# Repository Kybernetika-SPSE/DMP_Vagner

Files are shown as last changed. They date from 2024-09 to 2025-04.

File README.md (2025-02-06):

# Smart Hive

**Smart Hive** je projekt zaměřený na monitorování včelích úlů pomocí senzorů, které sbírají důležitá data o prostředí v úlech a jejich okolí. Data jsou přenášena přes I2C sběrnici do centrální (master) jednotky, která je dále odesílá do databáze. K těmto datům mohou uživatelé přistupovat online prostřednictvím webového rozhraní.

## Funkce
- **Sběr dat**: Senzory instalované ve včelích úlech monitorují teplotu, vlhkost, hmotnost úlu a hlukové znečištění.
- **Přenos dat**: Data z jednotlivých úlů jsou sbírána pomocí I2C komunikace a odesílána do centrální jednotky.
- **Uložení dat**: Centrální jednotka data ukládá do databáze.
- **Přístup k datům**: Uživatelé mohou přistupovat k datům online prostřednictvím webového rozhraní.

## Technické detaily
- **I2C komunikace**: Využívá se pro přenos dat mezi senzory v úlech a centrální jednotkou.
- **Databáze**: Data jsou ukládána do vzdálené databáze, která je přístupná uživatelům online.
- **Centrální jednotka**: Hlavní jednotka přijímá data od senzorů a zajišťuje jejich odesílání do databáze.
- **Webové rozhraní**: Poskytuje uživatelům přístup k živým datům a historickým záznamům.

## Požadavky
- **Hardware**: ESP32 s podporou I2C, senzory pro měření teploty, vlhkosti, hmotnosti a hluku, včelí úly.
- **Software**: Podpora I2C komunikace, databázový systém (např. MySQL, PostgreSQL), webový server pro přístup k datům.

## Použití
Po úspěšné instalaci systém začne shromažďovat a odesílat data ze senzorů v reálném čase. Uživatelé mohou k těmto datům přistupovat pomocí webového rozhraní, které umožňuje sledovat aktuální stav úlů a analyzovat historická data.

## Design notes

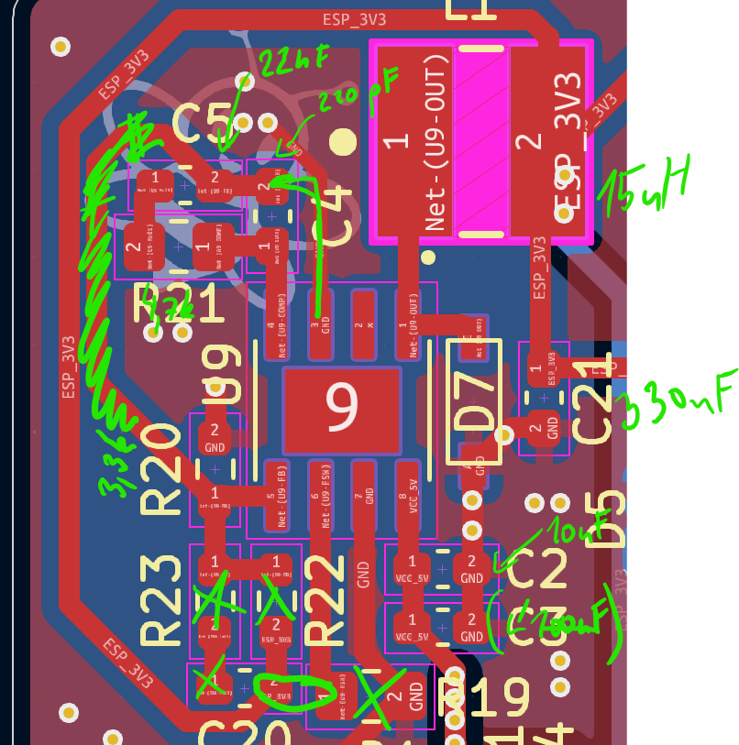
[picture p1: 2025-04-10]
PROJEKTOVÁ DATA/PCB/Master/Zapojení buck.png

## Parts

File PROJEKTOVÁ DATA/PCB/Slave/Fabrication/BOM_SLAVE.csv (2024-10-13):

Id | Designator | Footprint | Quantity | Designation | Supplier and ref
1 | J3 | PinSocket_1x07_P2.54mm_Vertical | 1 | Conn_01x07_Socket
2 | C17,C16 | C_0603_1608Metric_Pad1.08x0.95mm_HandSolder | 2 | 30pF
3 | C1,C3,C19,C4,C9,C5,C7 | C_0603_1608Metric_Pad1.08x0.95mm_HandSolder | 7 | 100nF
4 | C15,C20 | C_0603_1608Metric_Pad1.08x0.95mm_HandSolder | 2 | u1F
5 | R6,R7 | R_0603_1608Metric_Pad0.98x0.95mm_HandSolder | 2 | 5k1
6 | C6,C8,C14,C13,C11 | C_0603_1608Metric_Pad1.08x0.95mm_HandSolder | 5 | 1uF
7 | J1 | USB_C_Receptacle_GCT_USB4105-xx-A_16P_TopMnt_Horizontal | 1 | USB_C_Receptacle_USB2.0_16P
8 | ,,,,,,, |  | 8
9 | Q2 | SOT-23 | 1 | PNP
10 | U2 | SOP50P310X90-8N | 1 | TCA9406DC
11 | J2 | TerminalBlock_Phoenix_MPT-0,5-5-2.54_1x05_P2.54mm_Horizontal | 1 | Conn_01x05_Pin
12 | R12 | R_0603_1608Metric_Pad0.98x0.95mm_HandSolder | 1 | 120
13 | C18,C12 | C_0603_1608Metric_Pad1.08x0.95mm_HandSolder | 2 | 1uf
14 | J4 | PinHeader_1x04_P2.54mm_Vertical | 1 | Conn_01x04_Socket
15 | MK1 | InvenSense_ICS-43434-6_3.5x2.65mm | 1 | ICS-43434
16 | R17,R16 | R_0603_1608Metric_Pad0.98x0.95mm_HandSolder | 2 | R
17 | U3 | XDCR_BMP280 | 1 | BMP280
18 | J5 | PinHeader_1x07_P1.00mm_Vertical_SMD_Pin1Left | 1 | Conn_01x07_Socket
19 | U4 | SOIC127P599X175-8N | 1 | P82B715D
20 | SW1,SW2 | SW_PTS810_SJM_250_SMTR_LFS | 2 | PTS810_SJM_250_SMTR_LFS
21 | U5 | SOP-16_3.9x9.9mm_P1.27mm | 1 | HX711
22 | U1 | ESP32-S2-MINI-1 | 1 | ESP32-S3-MINI-1
23 | C2,C10 | C_0603_1608Metric_Pad1.08x0.95mm_HandSolder | 2 | 10uf
24 | R11,R9,R10 | R_0603_1608Metric_Pad0.98x0.95mm_HandSolder | 3 | 10k
25 | R8 | R_0603_1608Metric_Pad0.98x0.95mm_HandSolder | 1 | 0R
26 | U6 | SOIC127P599X175-8N | 1 | SN65HVD230
27 | D2 | Nexperia_CFP3_SOD-123W | 1 | 1N5819
28 | D3,D4,D1 | TVS_LESD5D5.0CT1G | 3 | LESD5D5.0CT1G
29 | R15 | R_0603_1608Metric_Pad0.98x0.95mm_HandSolder | 1 | 1k
30 | R13 | R_0603_1608Metric_Pad0.98x0.95mm_HandSolder | 1 | 20k
31 | R14 | R_0603_1608Metric_Pad0.98x0.95mm_HandSolder | 1 | 8k2
32 | D5 | LED_SK6812MINI_PLCC4_3.5x3.5mm_P1.75mm | 1 | SK6812MINI

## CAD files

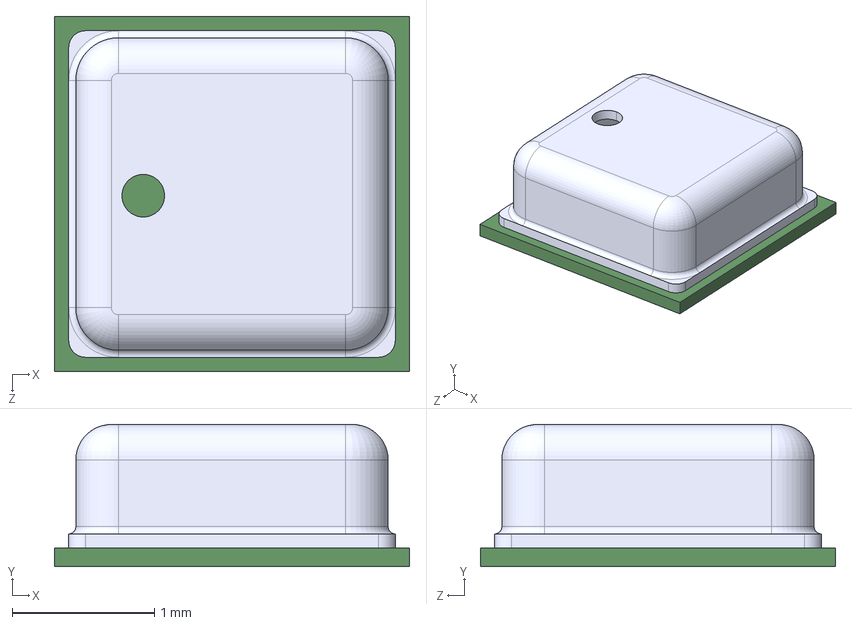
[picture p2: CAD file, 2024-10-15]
PROJEKTOVÁ DATA/PCB/Master/download/BME280/BME280.step
2.50 x 1.00 x 2.50 mm

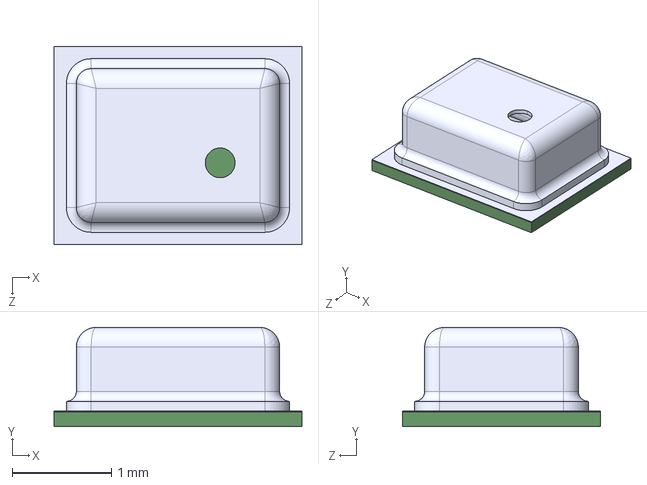
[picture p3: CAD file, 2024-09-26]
PROJEKTOVÁ DATA/PCB/Master/download/BMP280/BMP280.step
2.50 x 1.00 x 2.00 mm

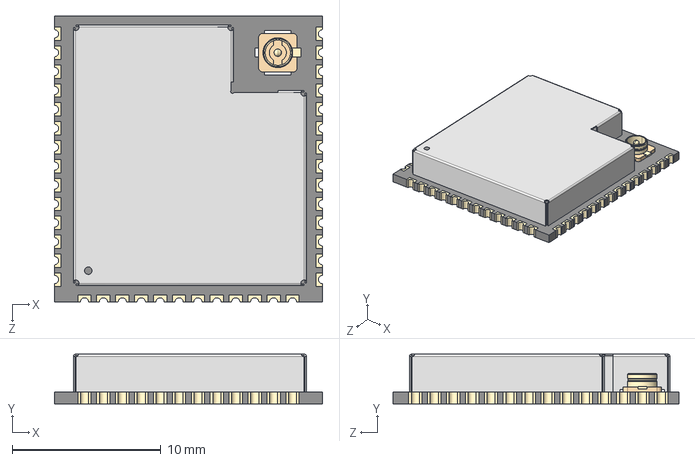
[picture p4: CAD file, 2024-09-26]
PROJEKTOVÁ DATA/PCB/Master/download/ESP32-S3-WROOM-1U/ESP32-S3-WROOM-1U.step
18.0 x 3.35 x 19.2 mm

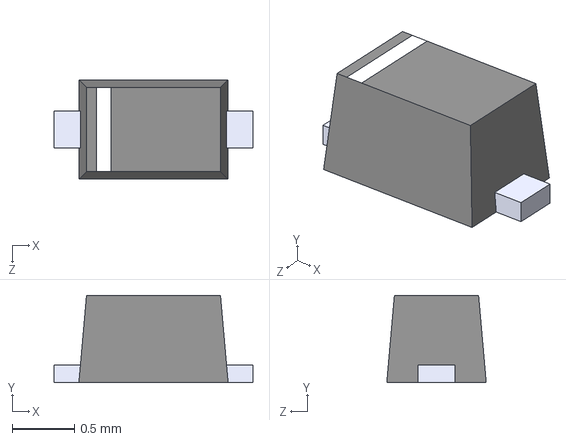
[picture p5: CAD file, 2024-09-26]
PROJEKTOVÁ DATA/PCB/Master/download/LESD5D5.0CT1G/LESD5D5.0CT1G.step
1.60 x 0.7 x 0.8 mm

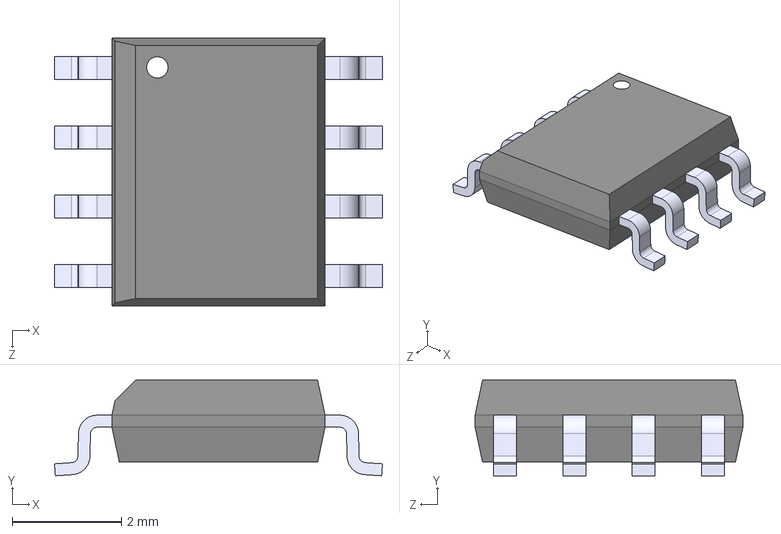
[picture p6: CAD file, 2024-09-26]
PROJEKTOVÁ DATA/PCB/Master/download/P82B715D/P82B715D.step
6.00 x 1.75 x 4.90 mm

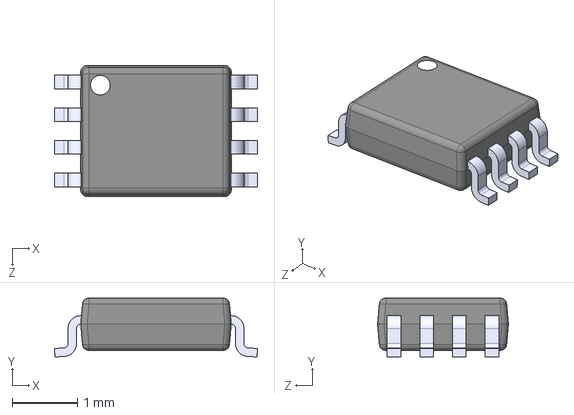
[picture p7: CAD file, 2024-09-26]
PROJEKTOVÁ DATA/PCB/Master/download/PCA9306DCURE4/PCA9306DCURE4.step
3.10 x 0.9 x 2.00 mm

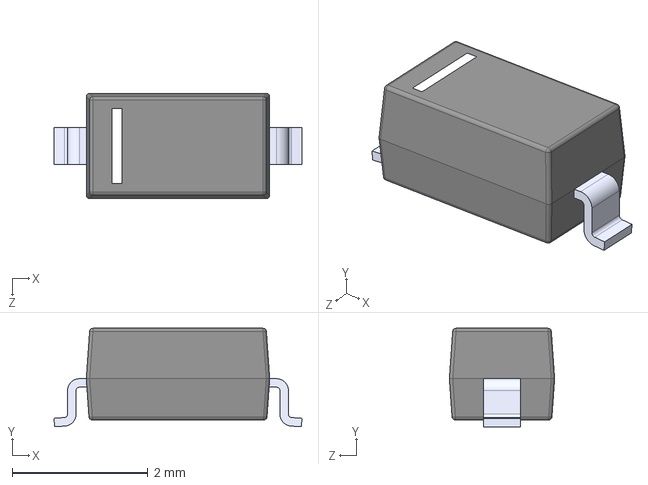
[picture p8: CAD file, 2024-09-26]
PROJEKTOVÁ DATA/PCB/Master/download/PMEG2010AEH/PMEG2010AEH.step
3.65 x 1.45 x 1.55 mm

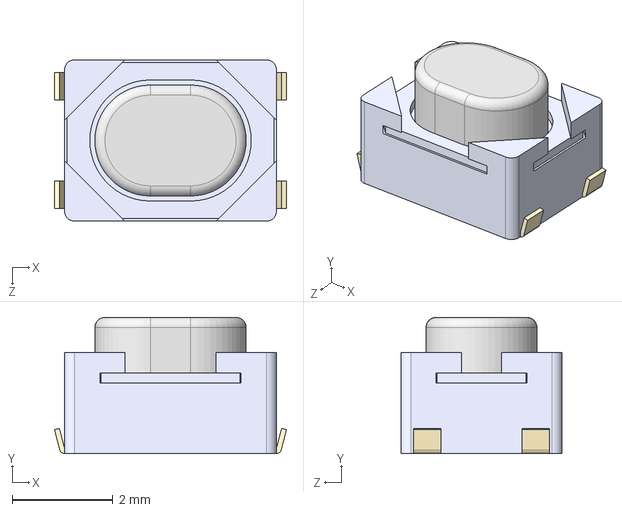
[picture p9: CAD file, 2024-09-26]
PROJEKTOVÁ DATA/PCB/Master/download/PTS810_SJM_250_SMTR_LFS/PTS810_SJM_250_SMTR_LFS.step
4.60 x 2.70 x 3.20 mm

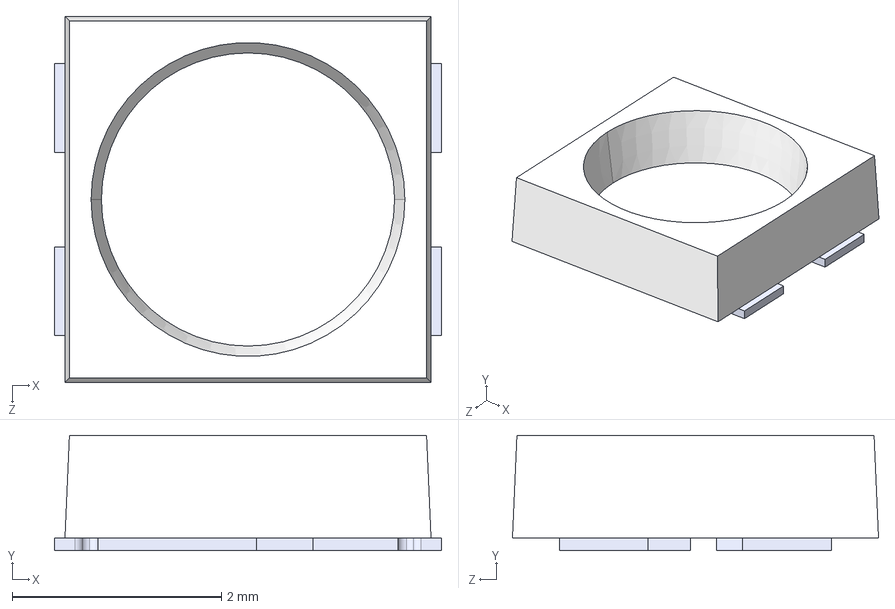
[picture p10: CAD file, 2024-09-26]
PROJEKTOVÁ DATA/PCB/Master/download/SK6812MINI-012/SK6812MINI-012.step
3.70 x 1.10 x 3.50 mm

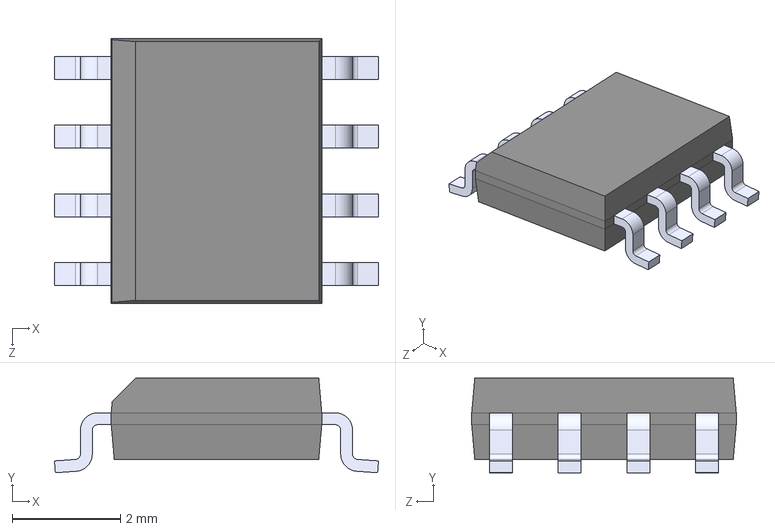
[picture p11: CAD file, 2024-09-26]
PROJEKTOVÁ DATA/PCB/Master/download/TJA1050/TJA1050.step
6.00 x 1.75 x 4.90 mm

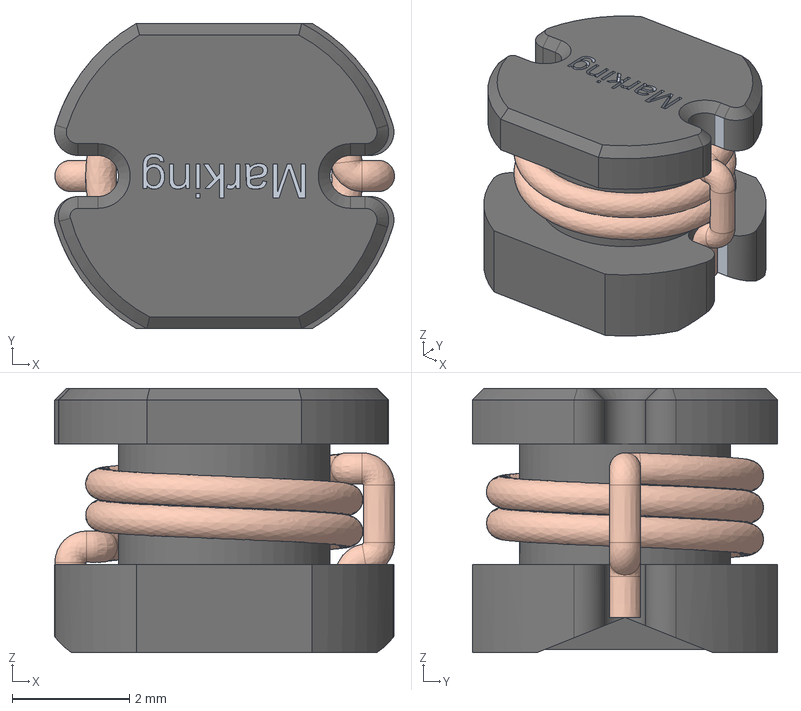
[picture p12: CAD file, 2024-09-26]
PROJEKTOVÁ DATA/PCB/Master/download/WE-PD2_5848/WE-PD2_5848.step
5.79 x 5.20 x 4.50 mm

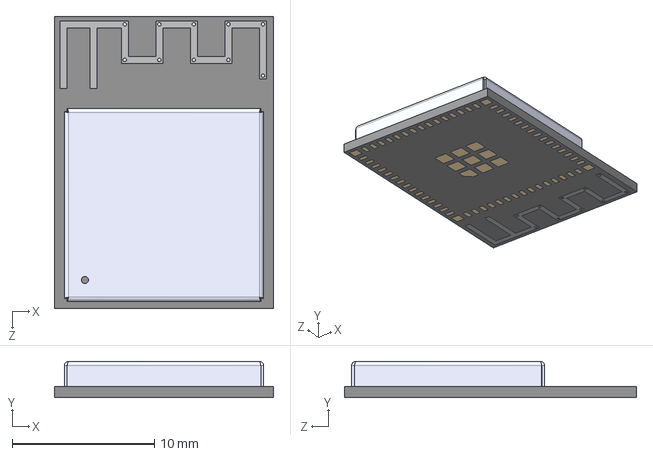
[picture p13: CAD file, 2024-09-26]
PROJEKTOVÁ DATA/PCB/Slave/Downloads/ESP32-S3-MINI-1-N8.step
15.4 x 2.55 x 20.5 mm

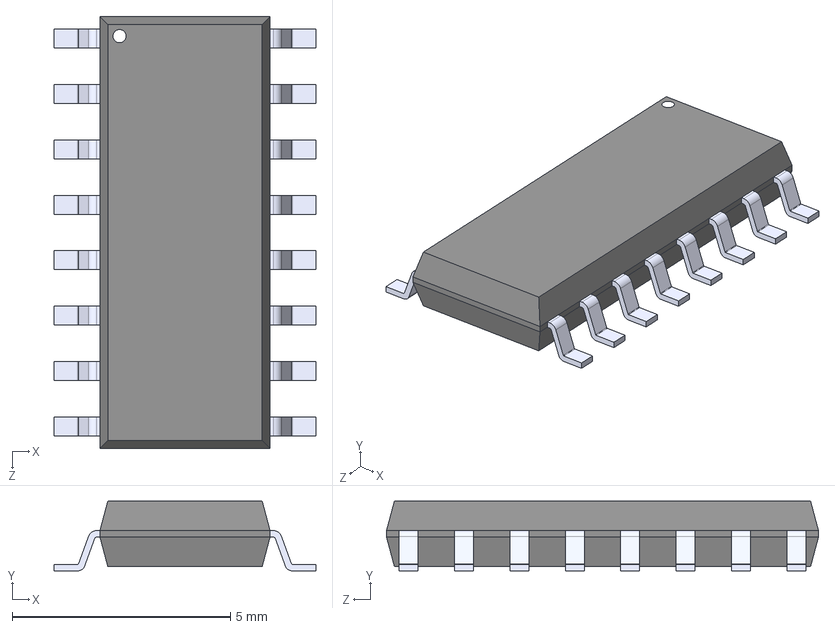
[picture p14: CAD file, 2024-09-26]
PROJEKTOVÁ DATA/PCB/Slave/Downloads/HX711/HX711.step
6.00 x 1.60 x 9.90 mm

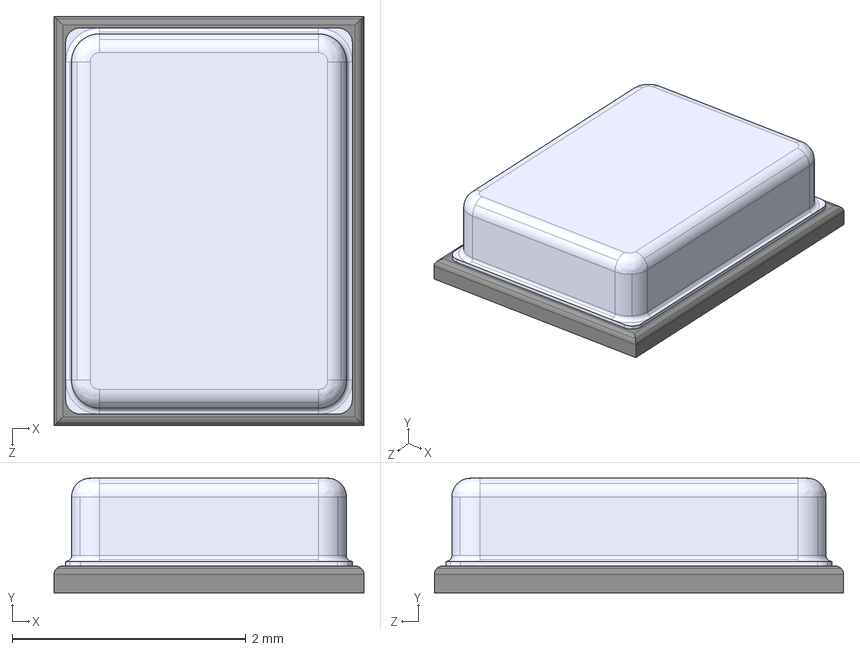
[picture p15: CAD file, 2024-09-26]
PROJEKTOVÁ DATA/PCB/Slave/Downloads/ICS-43434/ICS-43434.step
2.65 x 0.98 x 3.50 mm

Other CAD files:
PROJEKTOVÁ DATA/PCB/Slave/Master_Case_1.3mf
PROJEKTOVÁ DATA/PCB/Slave/Slave.step

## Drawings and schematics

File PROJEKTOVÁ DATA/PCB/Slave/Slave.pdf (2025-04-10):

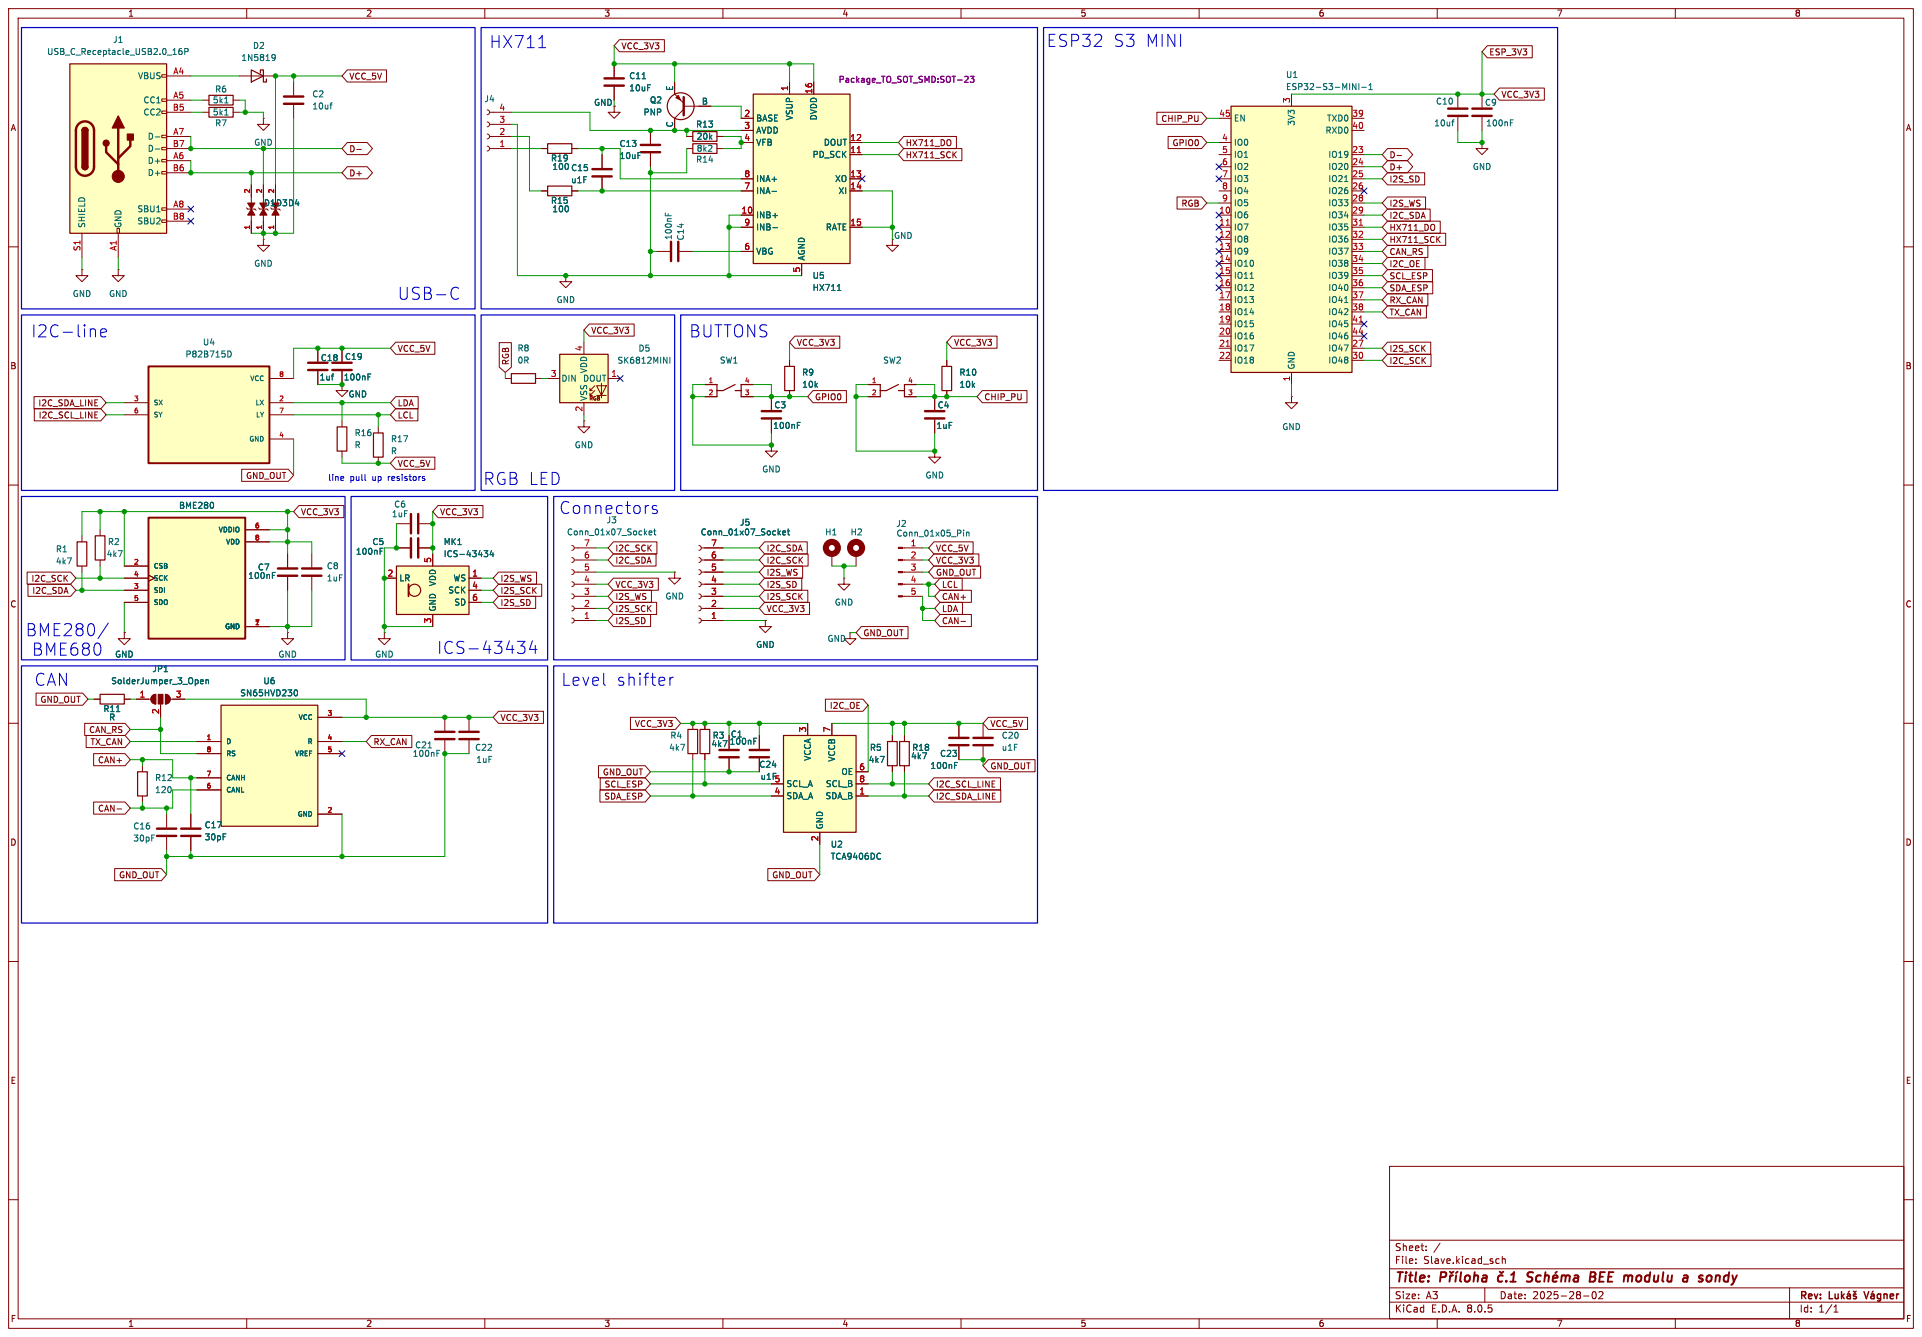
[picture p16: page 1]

File: Slave.kicad_sch Sheet: /
Id: 1/1 Title: þÿPYíloha þÿ

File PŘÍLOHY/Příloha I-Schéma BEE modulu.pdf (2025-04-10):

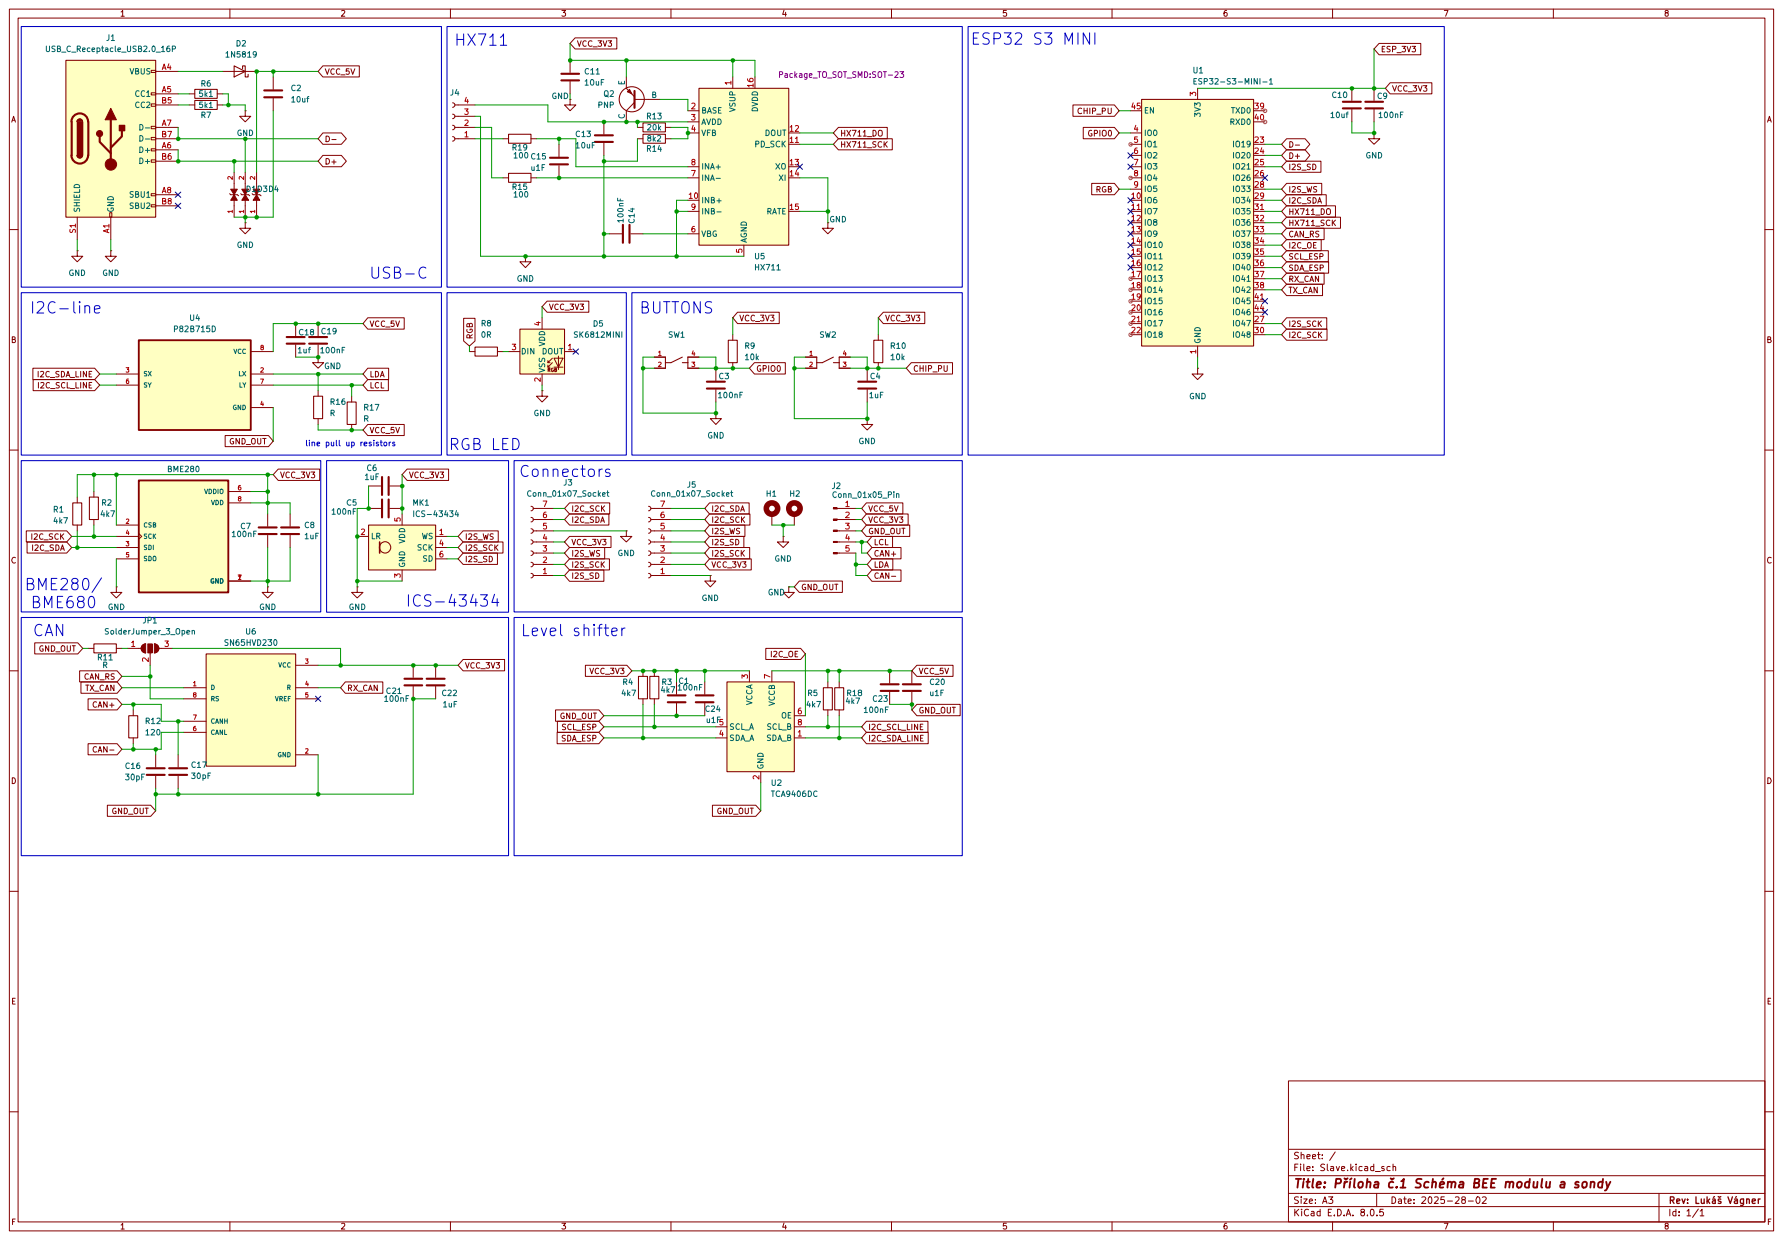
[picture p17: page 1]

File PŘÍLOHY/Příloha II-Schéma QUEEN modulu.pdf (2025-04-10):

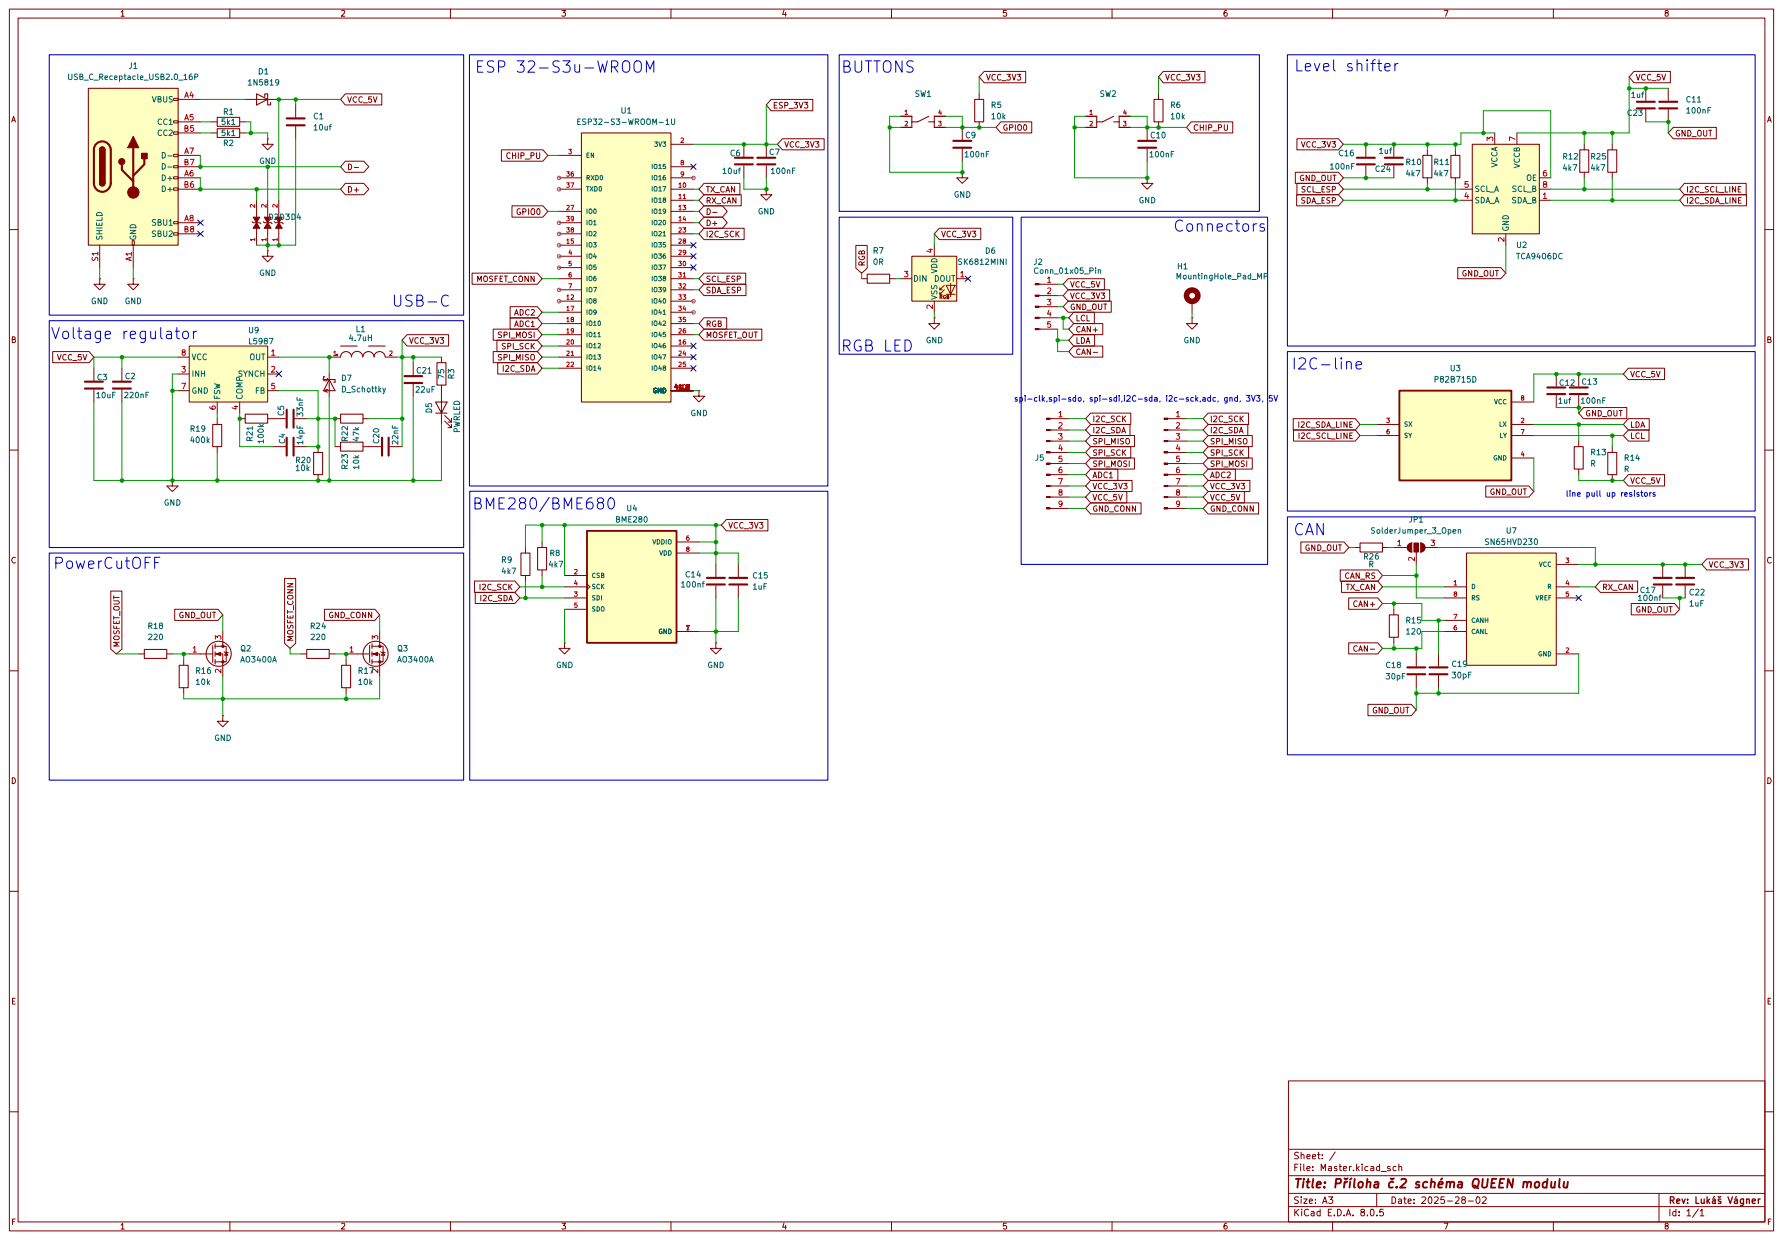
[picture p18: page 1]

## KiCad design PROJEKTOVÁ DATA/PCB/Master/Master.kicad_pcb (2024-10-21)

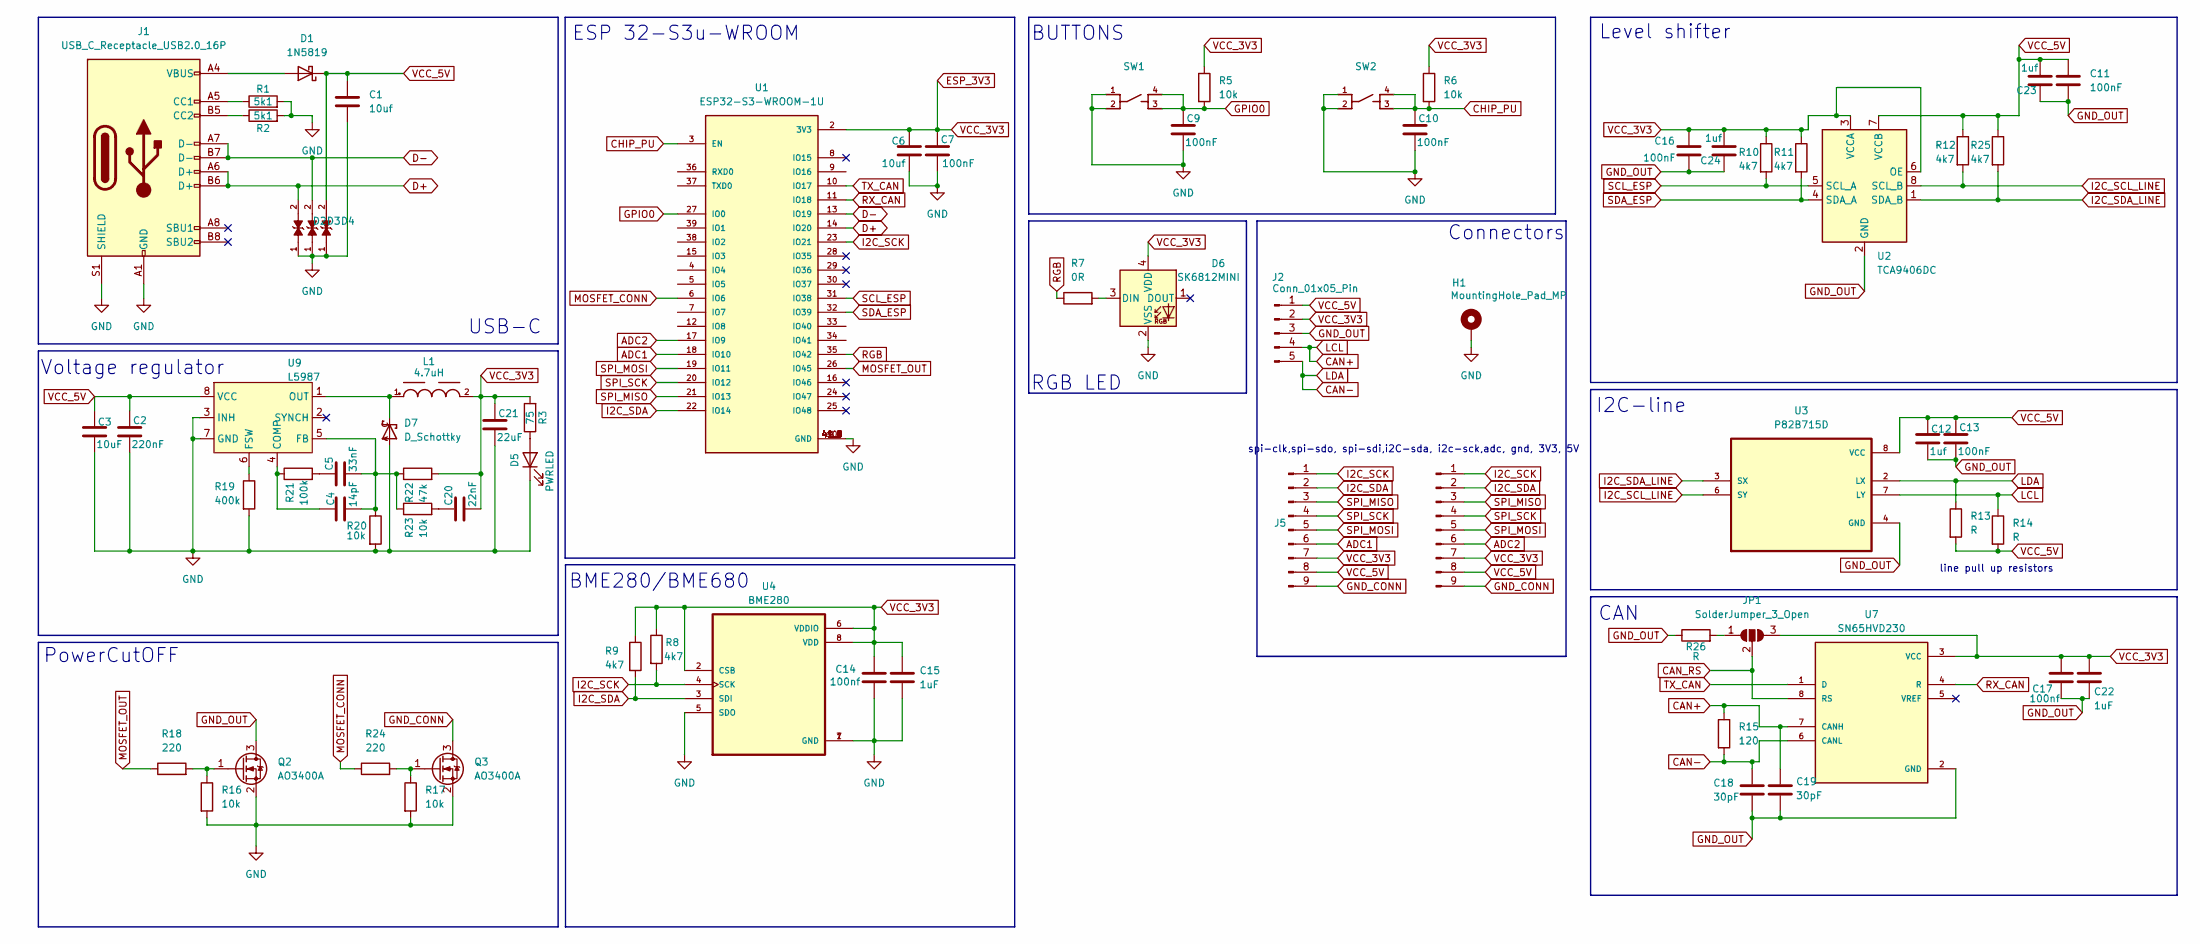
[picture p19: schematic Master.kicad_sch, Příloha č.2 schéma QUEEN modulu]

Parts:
C1, C6: 10uf; C_0603_1608Metric_Pad1.08x0.95mm_HandSolder
C2: 220nF; C_0603_1608Metric_Pad1.08x0.95mm_HandSolder
C3: 10uF; C_0603_1608Metric_Pad1.08x0.95mm_HandSolder
C4: 14pF; C_0603_1608Metric_Pad1.08x0.95mm_HandSolder
C5: 33nF; C_0603_1608Metric_Pad1.08x0.95mm_HandSolder
C7, C9, C10, C11, C13, C16: 100nF; C_0603_1608Metric_Pad1.08x0.95mm_HandSolder
C12, C23, C24: 1uf; C_0603_1608Metric_Pad1.08x0.95mm_HandSolder
C14, C17: 100nf; C_0603_1608Metric_Pad1.08x0.95mm_HandSolder
C15, C22: 1uF; C_0603_1608Metric_Pad1.08x0.95mm_HandSolder
C18, C19: 30pF; C_0603_1608Metric_Pad1.08x0.95mm_HandSolder
C20: 22nF; C_0603_1608Metric_Pad1.08x0.95mm_HandSolder
C21: 22uF; C_0603_1608Metric_Pad1.08x0.95mm_HandSolder
D1: 1N5819; Nexperia_CFP3_SOD-123W
D2, D3, D4: LESD5D5.0CT1G; TVS_LESD5D5.0CT1G; PARTREV O
D5: PWRLED; LED_0603_1608Metric_Pad1.05x0.95mm_HandSolder
D6: SK6812MINI; LED_SK6812MINI_PLCC4_3.5x3.5mm_P1.75mm
D7: D_Schottky; SOD-123
H1: MountingHole_Pad_MP; MountingHole_2.2mm_M2_Pad_Via
J1: USB_C_Receptacle_USB2.0_16P; USB_C_Receptacle_GCT_USB4105-xx-A_16P_TopMnt_Horizontal
J2: Conn_01x05_Pin; TerminalBlock_Phoenix_MPT-0,5-5-2.54_1x05_P2.54mm_Horizontal
J5, J6: Conn_01x09_Pin; PinHeader_1x09_P2.54mm_Vertical
JP1: SolderJumper_3_Open; SolderJumper-3_P1.3mm_Open_RoundedPad1.0x1.5mm
L1: 4.7uH; WE-PD2_5848; DigiKey_Part_Number 732-1272-2-ND
Q2, Q3: AO3400A; SOT-23
R1, R2: 5k1; R_0603_1608Metric_Pad0.98x0.95mm_HandSolder
R3: 75; R_0603_1608Metric_Pad0.98x0.95mm_HandSolder
R5, R6, R16, R17, R20, R23: 10k; R_0603_1608Metric_Pad0.98x0.95mm_HandSolder
R7: 0R; R_0603_1608Metric_Pad0.98x0.95mm_HandSolder
R8, R9, R10, R11, R12, R25: 4k7; R_0603_1608Metric_Pad0.98x0.95mm_HandSolder
R13, R14, R26: R; R_0603_1608Metric_Pad0.98x0.95mm_HandSolder
R15: 120; R_0603_1608Metric_Pad0.98x0.95mm_HandSolder
R18, R24: 220; R_0603_1608Metric_Pad0.98x0.95mm_HandSolder
R19: 400k; R_0805_2012Metric_Pad1.20x1.40mm_HandSolder
R21: 100k; R_0805_2012Metric_Pad1.20x1.40mm_HandSolder
R22: 47k; R_0603_1608Metric_Pad0.98x0.95mm_HandSolder
SW1, SW2: PTS810_SJM_250_SMTR_LFS; SW_PTS810_SJM_250_SMTR_LFS
U1: ESP32-S3-WROOM-1U; XCVR_ESP32-S3-WROOM-1U; PARTREV v0.6
U2: TCA9406DC; SOP50P310X90-8N
U3: P82B715D; SOIC127P599X175-8N
U4: BME280; PSON65P250X250X100-8N
U7: SN65HVD230; SOIC127P599X175-8N; PARTREV 02/2019
U9: L5987; SOIC127P600X170-9N

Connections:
ADC1: J5.6, U1.18 (IO10)
ADC2: J6.6, U1.17 (IO9)
CAN+: C19.1, J2.4, R14.1, R15.1, U3.7 (LY), U7.7 (CANH)
CAN-: C18.1, J2.5, R13.1, R15.2, U3.2 (LX), U7.6 (CANL)
CAN_RS: JP1.2 (C), U7.8 (RS)
CHIP_PU: C10.1, R6.2, SW2.3, SW2.4, U1.3 (EN)
D+: D2.2, J1.A6 (D+), J1.B6 (D+), U1.14 (IO20)
D-: D3.2, J1.A7 (D-), J1.B7 (D-), U1.13 (IO19)
ESP_3V3: C6.1, C7.1, C14.1, C15.1, C16.2, C17.1, C20.2, C21.1, C22.1, C24.2, D6.4 (VDD), J2.2, J5.7, J6.7, JP1.3 (B), L1.2, R3.2, R5.1, R6.1, R8.1, R9.1, R10.1, R11.1, R22.2, U1.2 (3V3), U2.3 (VCCA), U2.6 (OE), U4.2 (CSB), U4.6 (VDDIO), U4.8 (VDD), U7.3 (VCC)
GND: C1.2, C2.2, C3.2, C6.2, C7.2, C9.2, C10.2, C14.2, C15.2, C21.2, D2.1, D3.1, D4.1, D5.1 (K), D6.2 (VSS), D7.A, H1.1, J1.A1 (GND), J1.A12 (GND), J1.B1 (GND), J1.B12 (GND), J1.S1 (SHIELD), Q2.2 (S), Q3.2 (S), R1.2, R2.2, R16.2, R17.2, R19.2, R20.2, SW1.1, SW1.2, SW2.1, SW2.2, U1.1 (GND), U1.40 (GND), U1.41_1 (GND), U1.41_2 (GND), U1.41_3 (GND), U1.41_4 (GND), U1.41_5 (GND), U1.41_6 (GND), U1.41_7 (GND), U1.41_8 (GND), U1.41_9 (GND), U4.1 (GND), U4.5 (SDO), U4.7 (GND), U9.3 (INH), U9.7 (GND)
GND_CONN: J5.9, J6.9, Q3.3 (D)
GND_OUT: C11.2, C12.2, C13.2, C16.1, C17.2, C18.2, C19.2, C22.2, C23.1, C24.1, J2.3, Q2.3 (D), R26.1, U2.2 (GND), U3.4 (GND), U7.2 (GND)
GPIO0: C9.1, R5.2, SW1.3, SW1.4, U1.27 (IO0)
I2C_SCK: J5.1, J6.1, R8.2, U1.23 (IO21), U4.4 (SCK)
I2C_SCL_LINE: R12.2, U2.8 (SCL_B), U3.6 (SY)
I2C_SDA: J5.2, J6.2, R9.2, U1.22 (IO14), U4.3 (SDI)
I2C_SDA_LINE: R25.2, U2.1 (SDA_B), U3.3 (SX)
MOSFET_CONN: R24.1, U1.6 (IO6)
MOSFET_OUT: R18.1, U1.26 (IO45)
unnamed: C5.1, R21.2
unnamed: C20.1, R23.2
unnamed: D1.2 (A), J1.A4 (VBUS), J1.A9 (VBUS), J1.B4 (VBUS), J1.B9 (VBUS)
unnamed: D5.2 (A), R3.1
unnamed: D6.3 (DIN), R7.2
unnamed: J1.A5 (CC1), R1.1
unnamed: J1.B5 (CC2), R2.1
unnamed: JP1.1 (A), R26.2
unnamed: Q2.1 (G), R16.1, R18.2
unnamed: Q3.1 (G), R17.1, R24.2
unnamed: C4.1, R21.1, U9.4 (COMP)
unnamed: C4.2, C5.2, R20.1, R22.1, R23.1, U9.5 (FB)
unnamed: R19.1, U9.6 (FSW)
unnamed: D7.C, L1.1, U9.1 (OUT)
RGB: R7.1, U1.35 (IO42)
RX_CAN: U1.11 (IO18), U7.4 (R)
SCL_ESP: R10.2, U1.31 (IO38), U2.5 (SCL_A)
SDA_ESP: R11.2, U1.32 (IO39), U2.4 (SDA_A)
SPI_MISO: J5.3, J6.3, U1.21 (IO13)
SPI_MOSI: J5.5, J6.5, U1.19 (IO11)
SPI_SCK: J5.4, J6.4, U1.20 (IO12)
TX_CAN: U1.10 (IO17), U7.1 (D)
VCC_5V: C1.1, C2.1, C3.1, C11.1, C12.1, C13.1, C23.2, D1.1 (K), D4.2, J2.1, J5.8, J6.8, R12.1, R13.2, R14.2, R25.1, U2.7 (VCCB), U3.8 (VCC), U9.8 (VCC)

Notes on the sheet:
Connectors
Level shifter
CAN
BME280/BME680
line pull up resistors
Voltage regulator
USB-C
spi-clk,spi-sdo, spi-sdi,i2C-sda, i2c-sck,adc, gnd, 3V3, 5V
RGB LED
PowerCutOFF
ESP 32-S3u-WROOM
BUTTONS
I2C-line

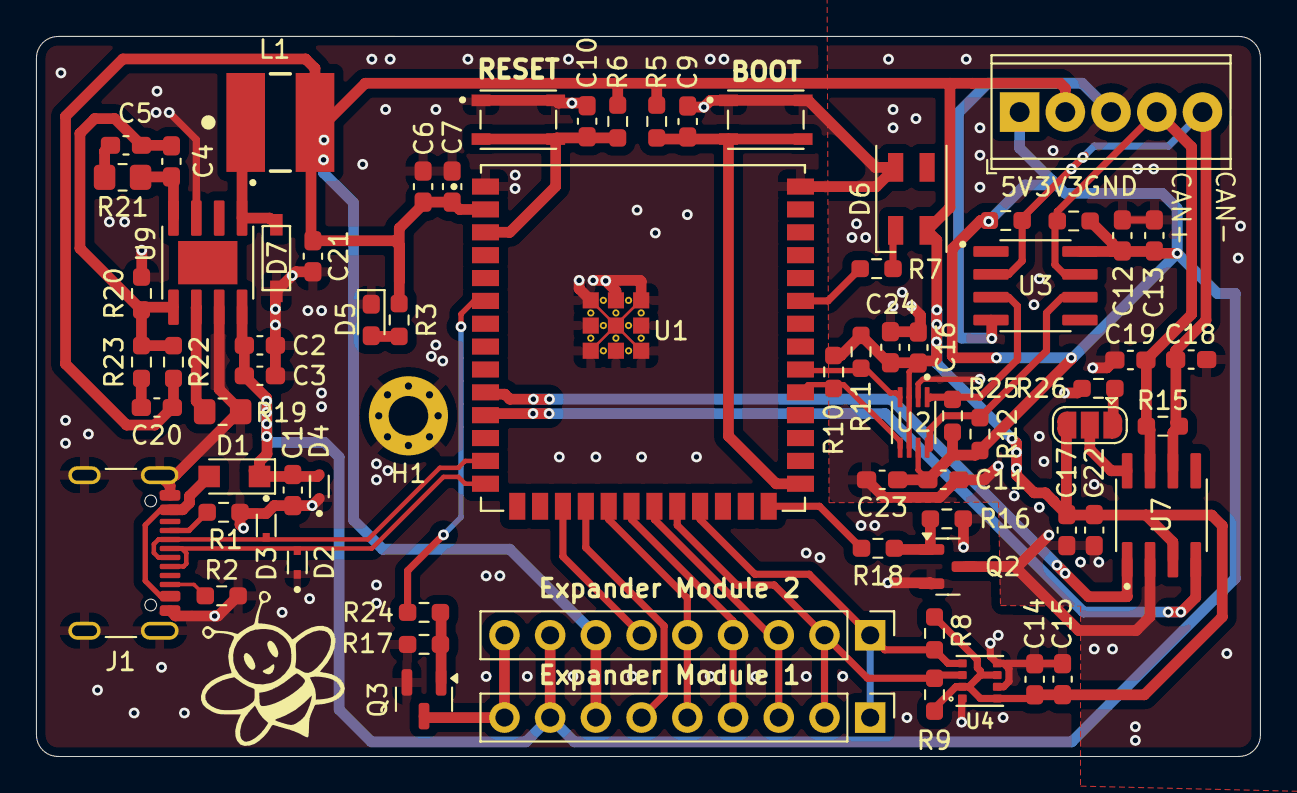
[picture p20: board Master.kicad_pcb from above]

Board: 2 copper layers, 68.0 x 40.0 mm, 72 parts (0 on the bottom side), 42 nets.

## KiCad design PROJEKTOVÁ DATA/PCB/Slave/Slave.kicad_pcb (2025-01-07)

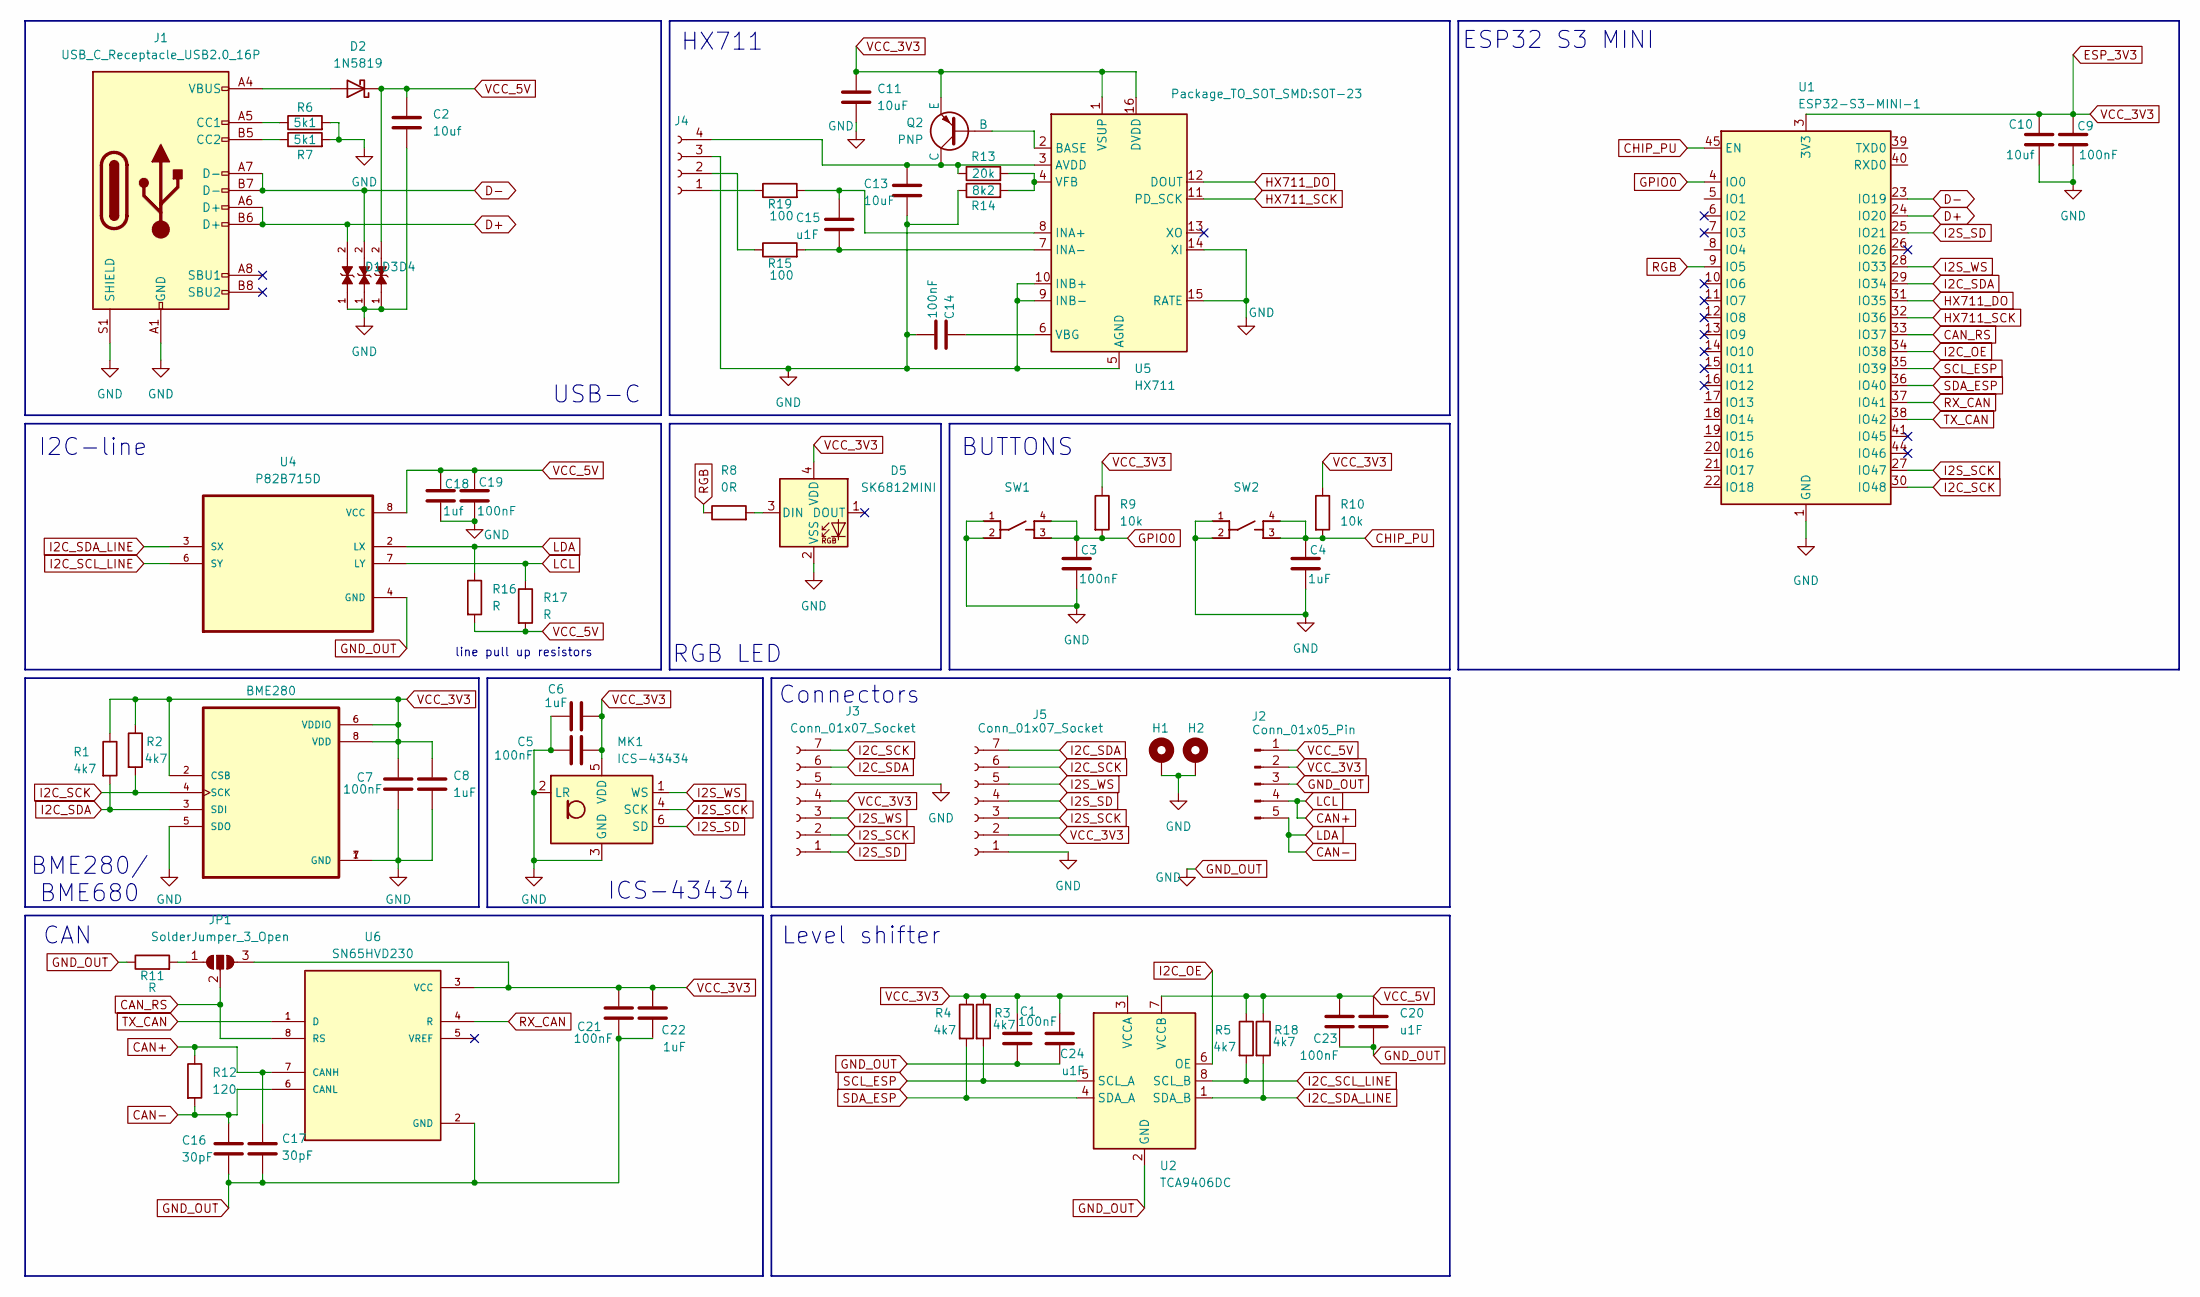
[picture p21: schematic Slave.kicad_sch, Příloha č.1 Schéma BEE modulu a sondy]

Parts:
C1, C3, C5, C7, C9, C14, C19, C21, C23: 100nF; C_0603_1608Metric_Pad1.08x0.95mm_HandSolder
C2, C10: 10uf; C_0603_1608Metric_Pad1.08x0.95mm_HandSolder
C4, C6, C8, C22: 1uF; C_0603_1608Metric_Pad1.08x0.95mm_HandSolder
C11, C13: 10uF; C_0603_1608Metric_Pad1.08x0.95mm_HandSolder
C15, C20, C24: u1F; C_0603_1608Metric_Pad1.08x0.95mm_HandSolder
C16, C17: 30pF; C_0603_1608Metric_Pad1.08x0.95mm_HandSolder
C18: 1uf; C_0603_1608Metric_Pad1.08x0.95mm_HandSolder
D1, D3, D4: LESD5D5.0CT1G; TVS_LESD5D5.0CT1G; PARTREV O
D2: 1N5819; Nexperia_CFP3_SOD-123W
D5: SK6812MINI; LED_SK6812MINI_PLCC4_3.5x3.5mm_P1.75mm
H1, H2: MountingHole_Pad_MP; MountingHole_2.2mm_M2_Pad_Via
J1: USB_C_Receptacle_USB2.0_16P; USB_C_Receptacle_GCT_USB4105-xx-A_16P_TopMnt_Horizontal
J2: Conn_01x05_Pin; TerminalBlock_Phoenix_MPT-0,5-5-2.54_1x05_P2.54mm_Horizontal
J3: Conn_01x07_Socket; PinSocket_1x07_P2.54mm_Vertical
J4: Conn_01x04_Socket; PinHeader_1x04_P2.54mm_Vertical
J5: Conn_01x07_Socket; PinHeader_1x07_P1.00mm_Vertical_SMD_Pin1Left
JP1: SolderJumper_3_Open; SolderJumper-3_P1.3mm_Open_RoundedPad1.0x1.5mm
MK1: ICS-43434; InvenSense_ICS-43434-6_3.5x2.65mm
Q2: PNP; SOT-23
R1, R2, R3, R4, R5, R18: 4k7; R_0603_1608Metric_Pad0.98x0.95mm_HandSolder
R6, R7: 5k1; R_0603_1608Metric_Pad0.98x0.95mm_HandSolder
R8: 0R; R_0603_1608Metric_Pad0.98x0.95mm_HandSolder
R9, R10: 10k; R_0603_1608Metric_Pad0.98x0.95mm_HandSolder
R11, R16, R17: R; R_0603_1608Metric_Pad0.98x0.95mm_HandSolder
R12: 120; R_0603_1608Metric_Pad0.98x0.95mm_HandSolder
R13: 20k; R_0603_1608Metric_Pad0.98x0.95mm_HandSolder
R14: 8k2; R_0603_1608Metric_Pad0.98x0.95mm_HandSolder
R15, R19: 100; R_0603_1608Metric_Pad0.98x0.95mm_HandSolder
SW1, SW2: PTS810_SJM_250_SMTR_LFS; SW_PTS810_SJM_250_SMTR_LFS
U1: ESP32-S3-MINI-1; XCVR_ESP32-S3-MINI-1-N8
U2: TCA9406DC; SOP50P310X90-8N
U4: P82B715D; SOIC127P599X175-8N
U5: HX711; SOP-16_3.9x9.9mm_P1.27mm
U6: SN65HVD230; SOIC127P599X175-8N; PARTREV 02/2019
U7: BME280; PSON65P250X250X100-8N

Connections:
CAN+: C17.1, J2.4, R12.1, R17.1, U4.7 (LY), U6.7 (CANH)
CAN-: C16.1, J2.5, R12.2, R16.1, U4.2 (LX), U6.6 (CANL)
CAN_RS: JP1.2 (C), U1.33 (IO37), U6.8 (RS)
CHIP_PU: C4.1, R10.2, SW2.3, SW2.4, U1.45 (EN)
D+: D1.2, J1.A6 (D+), J1.B6 (D+), U1.24 (IO20)
D-: D3.2, J1.A7 (D-), J1.B7 (D-), U1.23 (IO19)
ESP_3V3: C1.2, C5.2, C6.2, C7.1, C8.1, C9.1, C10.1, C11.1, C21.1, C22.1, C24.1, D5.4 (VDD), J2.2, J3.4, J5.2, JP1.3 (B), MK1.5 (VDD), Q2.3 (E), R1.1, R2.1, R3.1, R4.1, R9.1, R10.1, U1.3 (3V3), U2.3 (VCCA), U5.1 (VSUP), U5.16 (DVDD), U6.3 (VCC), U7.2 (CSB), U7.6 (VDDIO), U7.8 (VDD)
GND_OUT: C1.1, C2.2, C3.2, C4.2, C5.1, C6.1, C7.2, C8.2, C9.2, C10.2, C11.2, C13.2, C14.2, C16.2, C17.2, C18.2, C19.2, C20.2, C21.2, C22.2, C23.1, C24.2, D1.1, D3.1, D4.1, D5.2 (VSS), H1.1, H2.1, J1.A1 (GND), J1.A12 (GND), J1.B1 (GND), J1.B12 (GND), J1.S1 (SHIELD), J2.3, J3.5, J4.3, J5.1, MK1.2 (LR), MK1.3 (GND), R6.2, R7.2, R11.1, R14.1, SW1.1, SW1.2, SW2.1, SW2.2, U1.1 (GND), U1.2 (GND), U1.42 (GND), U1.43 (GND), U1.46 (GND), U1.47 (GND), U1.48 (GND), U1.49 (GND), U1.50 (GND), U1.51 (GND), U1.52 (GND), U1.53 (GND), U1.54 (GND), U1.55 (GND), U1.56 (GND), U1.57 (GND), U1.58 (GND), U1.59 (GND), U1.60 (GND), U1.61 (GND), U1.62 (GND), U1.63 (GND), U1.64 (GND), U1.65 (GND), U2.2 (GND), U4.4 (GND), U5.5 (AGND), U5.9 (INB-), U5.10 (INB+), U5.14 (XI), U5.15 (RATE), U6.2 (GND), U7.1 (GND), U7.5 (SDO), U7.7 (GND)
GPIO0: C3.1, R9.2, SW1.3, SW1.4, U1.4 (IO0)
HX711_DO: U1.31 (IO35), U5.12 (DOUT)
HX711_SCK: U1.32 (IO36), U5.11 (PD_SCK)
I2C_OE: U1.34 (IO38), U2.6 (OE)
I2C_SCK: J3.7, J5.6, R2.2, U1.30 (IO48), U7.4 (SCK)
I2C_SCL_LINE: R5.2, U2.8 (SCL_B), U4.6 (SY)
I2C_SDA: J3.6, J5.7, R1.2, U1.29 (IO34), U7.3 (SDI)
I2C_SDA_LINE: R18.2, U2.1 (SDA_B), U4.3 (SX)
I2S_SCK: J3.2, J5.3, MK1.4 (SCK), U1.27 (IO47)
I2S_SD: J3.1, J5.4, MK1.6 (SD), U1.25 (IO21)
I2S_WS: J3.3, J5.5, MK1.1 (WS), U1.28 (IO33)
unnamed: D2.2 (A), J1.A4 (VBUS), J1.A9 (VBUS), J1.B4 (VBUS), J1.B9 (VBUS)
unnamed: D5.3 (DIN), R8.2
unnamed: J1.A5 (CC1), R6.1
unnamed: J1.B5 (CC2), R7.1
unnamed: J4.1, R19.1
unnamed: J4.2, R15.1
unnamed: C13.1, J4.4, Q2.1 (C), R13.1, U5.3 (AVDD)
unnamed: JP1.1 (A), R11.2
unnamed: Q2.2 (B), U5.2 (BASE)
unnamed: C15.1, R19.2, U5.8 (INA+)
unnamed: C15.2, R15.2, U5.7 (INA-)
unnamed: C14.1, U5.6 (VBG)
unnamed: R13.2, R14.2, U5.4 (VFB)
RGB: R8.1, U1.9 (IO5)
RX_CAN: U1.37 (IO41), U6.4 (R)
SCL_ESP: R3.2, U1.35 (IO39), U2.5 (SCL_A)
SDA_ESP: R4.2, U1.36 (IO40), U2.4 (SDA_A)
TX_CAN: U1.38 (IO42), U6.1 (D)
VCC_5V: C2.1, C18.1, C19.1, C20.1, C23.2, D2.1 (K), D4.2, J2.1, R5.1, R16.2, R17.2, R18.1, U2.7 (VCCB), U4.8 (VCC)

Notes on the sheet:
RGB LED
Connectors
BUTTONS
I2C-line
line pull up resistors
HX711
CAN
ICS-43434
Level shifter
BME280/ BME680
ESP32 S3 MINI
USB-C

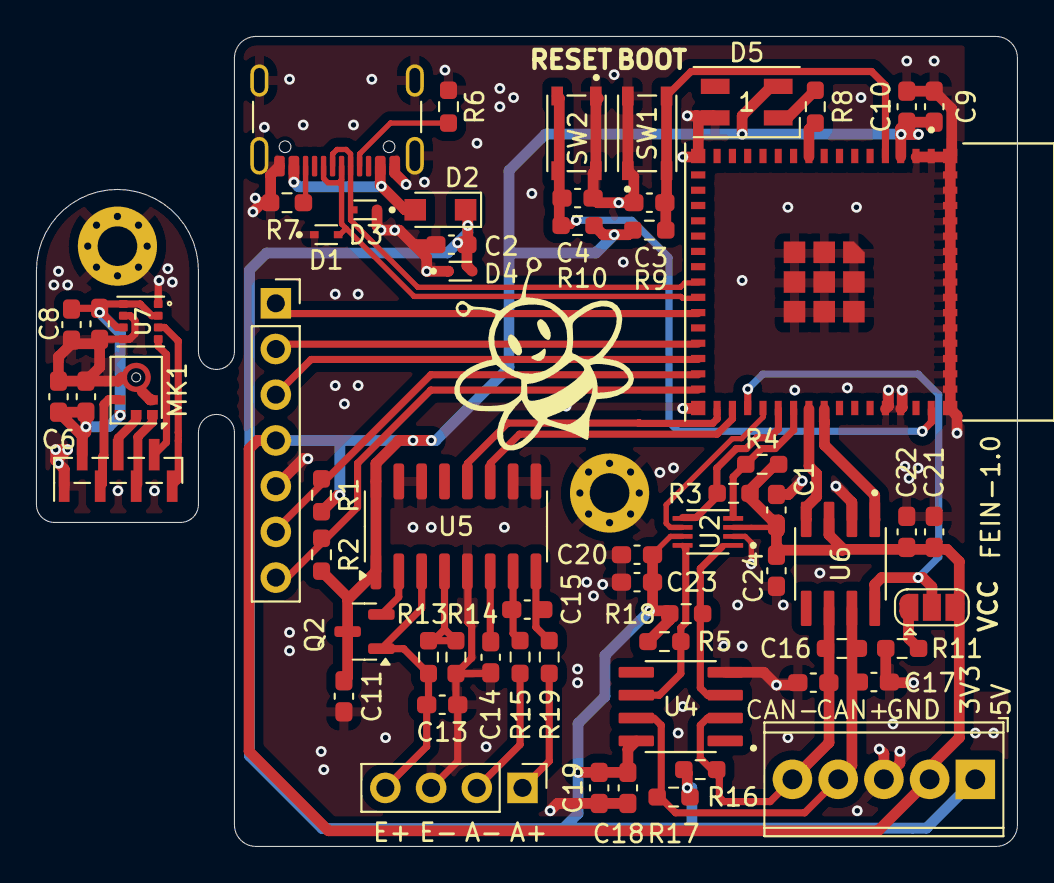
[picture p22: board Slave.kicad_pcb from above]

Board: 2 copper layers, 54.5 x 45.0 mm, 65 parts (0 on the bottom side), 38 nets.

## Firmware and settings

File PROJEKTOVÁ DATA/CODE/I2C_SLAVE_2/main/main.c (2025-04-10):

#include <stdio.h>
#include <string.h>
#include <inttypes.h> // For PRId32
#include "freertos/FreeRTOS.h"
#include "freertos/task.h"
#include "driver/gpio.h"
#include "driver/i2c.h"
#include "esp_log.h"
#include "led_strip.h"
#include "esp_rom_sys.h"

uint8_t slave_id = 2; // Replace 1 with the unique ID for this slave

#define I2C_SLAVE_SCL_IO          39  // GPIO for I2C clock
#define I2C_SLAVE_SDA_IO          40  // GPIO for I2C data
#define I2C_SLAVE_NUM             I2C_NUM_0
#define I2C_SLAVE_ADDRESS         slave_id
#define I2C_SLAVE_RX_BUF_LEN      512
#define I2C_SLAVE_TX_BUF_LEN      512

#define I2C_OUT                   38  // Define the GPIO pin number

#define HX711_DT_PIN              35  // GPIO for HX711 Data (DT)
#define HX711_SCK_PIN             36  // GPIO for HX711 Clock (SCK)

// BME280 I2C Address and Registers
#define BME280_I2C_ADDRESS  0x76
#define BME280_REG_ID       0xD0
#define BME280_REG_CALIB    0x88
#define BME280_REG_CTRL_MEAS 0xF4
#define BME280_REG_CTRL_HUM 0xF2
#define BME280_REG_DATA     0xF7

static bool bme280_connected = false; // Flag to indicate BME280 connection
int bmeFAIL = 0; // Counter for BME280 failures


// I2C Pins
#define SDA_GPIO 34
#define SCL_GPIO 48



#define SK6812_PIN                5   // GPIO for SK6812 RGB LED

static const char *TAG = "I2C_HX711_SK6812_BME280";

static led_strip_handle_t led_strip;

// Calibration parameters
typedef struct {
    uint16_t dig_T1;
    int16_t dig_T2;
    int16_t dig_T3;
    uint16_t dig_P1;
    int16_t dig_P2;
    int16_t dig_P3;
    int16_t dig_P4;
    int16_t dig_P5;
    int16_t dig_P6;
    int16_t dig_P7;
    int16_t dig_P8;
    int16_t dig_P9;
    uint8_t dig_H1;
    int16_t dig_H2;
    uint8_t dig_H3;
    int16_t dig_H4;
    int16_t dig_H5;
    int8_t dig_H6;
} bme280_calib_data_t;

static bme280_calib_data_t calib_data;
static int32_t t_fine = 0;

void i2c_master_init() {
    i2c_config_t config = {
        .mode = I2C_MODE_MASTER,
        .sda_io_num = SDA_GPIO,
        .scl_io_num = SCL_GPIO,
        .sda_pullup_en = GPIO_PULLUP_ENABLE,
        .scl_pullup_en = GPIO_PULLUP_ENABLE,
        .master.clk_speed = 100000,
    };
    ESP_ERROR_CHECK(i2c_param_config(I2C_NUM_1, &config));
    ESP_ERROR_CHECK(i2c_driver_install(I2C_NUM_1, I2C_MODE_MASTER, 0, 0, 0));
    ESP_LOGI(TAG, "I2C initialized on SDA: %d, SCL: %d", SDA_GPIO, SCL_GPIO);
}

esp_err_t bme280_read_register(uint8_t reg_addr, uint8_t *data, size_t len) {
    i2c_cmd_handle_t cmd = i2c_cmd_link_create();
    ESP_ERROR_CHECK(i2c_master_start(cmd));
    ESP_ERROR_CHECK(i2c_master_write_byte(cmd, (BME280_I2C_ADDRESS << 1) | I2C_MASTER_WRITE, true));
    ESP_ERROR_CHECK(i2c_master_write_byte(cmd, reg_addr, true));
    ESP_ERROR_CHECK(i2c_master_start(cmd));
    ESP_ERROR_CHECK(i2c_master_write_byte(cmd, (BME280_I2C_ADDRESS << 1) | I2C_MASTER_READ, true));
    ESP_ERROR_CHECK(i2c_master_read(cmd, data, len, I2C_MASTER_LAST_NACK));
    ESP_ERROR_CHECK(i2c_master_stop(cmd));
    esp_err_t ret = i2c_master_cmd_begin(I2C_NUM_1, cmd, pdMS_TO_TICKS(1000));
    i2c_cmd_link_delete(cmd);
    return ret;
}

void bme280_write_register(uint8_t reg_addr, uint8_t value) {
    i2c_cmd_handle_t cmd = i2c_cmd_link_create();
    ESP_ERROR_CHECK(i2c_master_start(cmd));
    ESP_ERROR_CHECK(i2c_master_write_byte(cmd, (BME280_I2C_ADDRESS << 1) | I2C_MASTER_WRITE, true));
    ESP_ERROR_CHECK(i2c_master_write_byte(cmd, reg_addr, true));
    ESP_ERROR_CHECK(i2c_master_write_byte(cmd, value, true));
    ESP_ERROR_CHECK(i2c_master_stop(cmd));
    ESP_ERROR_CHECK(i2c_master_cmd_begin(I2C_NUM_1, cmd, pdMS_TO_TICKS(1000)));
    i2c_cmd_link_delete(cmd);
}

void bme280_read_calibration_data() {
    uint8_t calib[26];
    bme280_read_register(BME280_REG_CALIB, calib, 26);

    calib_data.dig_T1 = (uint16_t)(calib[0] | (calib[1] << 8));
    calib_data.dig_T2 = (int16_t)(calib[2] | (calib[3] << 8));
    calib_data.dig_T3 = (int16_t)(calib[4] | (calib[5] << 8));
    calib_data.dig_P1 = (uint16_t)(calib[6] | (calib[7] << 8));
    calib_data.dig_P2 = (int16_t)(calib[8] | (calib[9] << 8));
    calib_data.dig_P3 = (int16_t)(calib[10] | (calib[11] << 8));
    calib_data.dig_P4 = (int16_t)(calib[12] | (calib[13] << 8));
    calib_data.dig_P5 = (int16_t)(calib[14] | (calib[15] << 8));
    calib_data.dig_P6 = (int16_t)(calib[16] | (calib[17] << 8));
    calib_data.dig_P7 = (int16_t)(calib[18] | (calib[19] << 8));
    calib_data.dig_P8 = (int16_t)(calib[20] | (calib[21] << 8));
    calib_data.dig_P9 = (int16_t)(calib[22] | (calib[23] << 8));
    calib_data.dig_H1 = calib[25];
    
    uint8_t h_calib[7];
    bme280_read_register(0xE1, h_calib, 7);
    calib_data.dig_H2 = (int16_t)(h_calib[0] | (h_calib[1] << 8));
    calib_data.dig_H3 = h_calib[2];
    calib_data.dig_H4 = (int16_t)((h_calib[3] << 4) | (h_calib[4] & 0x0F));
    calib_data.dig_H5 = (int16_t)((h_calib[5] << 4) | (h_calib[4] >> 4));
    calib_data.dig_H6 = (int8_t)h_calib[6];
}

int32_t compensate_temperature(int32_t adc_T) {
    int32_t var1 = (((adc_T >> 3) - ((int32_t)calib_data.dig_T1 << 1)) * ((int32_t)calib_data.dig_T2)) >> 11;
    int32_t var2 = (((((adc_T >> 4) - ((int32_t)calib_data.dig_T1)) * ((adc_T >> 4) - ((int32_t)calib_data.dig_T1))) >> 12) *
                    ((int32_t)calib_data.dig_T3)) >>
                   14;
    t_fine = var1 + var2;
    return (t_fine * 5 + 128) >> 8;
}

uint32_t compensate_pressure(int32_t adc_P) {
    int64_t var1 = ((int64_t)t_fine) - 128000;
    int64_t var2 = var1 * var1 * (int64_t)calib_data.dig_P6;
    var2 = var2 + ((var1 * (int64_t)calib_data.dig_P5) << 17);
    var2 = var2 + (((int64_t)calib_data.dig_P4) << 35);
    var1 = ((var1 * var1 * (int64_t)calib_data.dig_P3) >> 8) + ((var1 * (int64_t)calib_data.dig_P2) << 12);
    var1 = (((((int64_t)1) << 47) + var1)) * ((int64_t)calib_data.dig_P1) >> 33;

    if (var1 == 0) {
        return 0; // avoid division by zero
    }

    int64_t p = 1048576 - adc_P;
    p = (((p << 31) - var2) * 3125) / var1;
    var1 = (((int64_t)calib_data.dig_P9) * (p >> 13) * (p >> 13)) >> 25;
    var2 = (((int64_t)calib_data.dig_P8) * p) >> 19;

    p = ((p + var1 + var2) >> 8) + (((int64_t)calib_data.dig_P7) << 4);
    return (uint32_t)p / 256;
}

uint32_t compensate_humidity(int32_t adc_H) {
    int32_t v_x1_u32r = t_fine - 76800;
    v_x1_u32r = (((((adc_H << 14) - (((int32_t)calib_data.dig_H4) << 20) - (((int32_t)calib_data.dig_H5) * v_x1_u32r)) + 16384) >> 15) *
                 (((((((v_x1_u32r * ((int32_t)calib_data.dig_H6)) >> 10) * (((v_x1_u32r * ((int32_t)calib_data.dig_H3)) >> 11) + 32768)) >> 10) + 2097152) *
                   ((int32_t)calib_data.dig_H2) +
                   8192) >>
                  14));
    v_x1_u32r = (v_x1_u32r - (((((v_x1_u32r >> 15) * (v_x1_u32r >> 15)) >> 7) * ((int32_t)calib_data.dig_H1)) >> 4));
    v_x1_u32r = (v_x1_u32r < 0 ? 0 : v_x1_u32r);
    v_x1_u32r = (v_x1_u32r > 419430400 ? 419430400 : v_x1_u32r);
    return (uint32_t)(v_x1_u32r >> 12);
}

void bme280_init() {
    uint8_t chip_id;
    esp_err_t err = bme280_read_register(BME280_REG_ID, &chip_id, 1);
    if (err == ESP_OK && chip_id == 0x60) { // Check for valid BME280 Chip ID
        ESP_LOGI(TAG, "BME280 detected with Chip ID: 0x%X", chip_id);
        bme280_connected = true;

        bme280_read_calibration_data();
        bme280_write_register(BME280_REG_CTRL_HUM, 0x01);  // Humidity oversampling x1
        bme280_write_register(BME280_REG_CTRL_MEAS, 0x27); // Temp and Pressure oversampling x1, Mode normal
    } else {
        ESP_LOGW(TAG, "BME280 not detected! Error: %s", esp_err_to_name(err));
        bme280_connected = false;
    }
}

void configure_gpio_as_output()
{
    gpio_config_t io_conf = {
        .pin_bit_mask = (1ULL << I2C_OUT), // Set the pin to configure
        .mode = GPIO_MODE_OUTPUT,                 // Set as output mode
        .pull_up_en = GPIO_PULLUP_DISABLE,        // Disable pull-up
        .pull_down_en = GPIO_PULLDOWN_DISABLE,    // Disable pull-down
        .intr_type = GPIO_INTR_DISABLE            // No interrupt
    };

    ESP_ERROR_CHECK(gpio_config(&io_conf)); // Configure the GPIO
    ESP_LOGI("GPIO", "Configured GPIO %d as output.", I2C_OUT);
}

void set_gpio_high()
{
    gpio_set_level(I2C_OUT, 1); // Set GPIO high
    ESP_LOGI("GPIO", "GPIO %d set to HIGH.", I2C_OUT);
}


/* HX711 Initialization */
void hx711_init()
{
    gpio_config_t io_conf = {
        .pin_bit_mask = (1ULL << HX711_DT_PIN) | (1ULL << HX711_SCK_PIN),
        .mode = GPIO_MODE_OUTPUT,
        .pull_up_en = GPIO_PULLUP_DISABLE,
        .pull_down_en = GPIO_PULLDOWN_DISABLE,
        .intr_type = GPIO_INTR_DISABLE
    };

    ESP_ERROR_CHECK(gpio_config(&io_conf));
    gpio_set_direction(HX711_DT_PIN, GPIO_MODE_INPUT); // Set DT as input
    gpio_set_level(HX711_SCK_PIN, 0);                 // Ensure clock starts low
}

/* HX711 Read Function */
int32_t hx711_read()
{
    int32_t data = 0;

    // Wait until the HX711 is ready
    while (gpio_get_level(HX711_DT_PIN) == 1) {
        vTaskDelay(pdMS_TO_TICKS(1)); // Small delay
    }

    // Read 24 bits of data from HX711
    for (int i = 0; i < 24; i++) {
        gpio_set_level(HX711_SCK_PIN, 1);
        esp_rom_delay_us(1);
        data = (data << 1) | gpio_get_level(HX711_DT_PIN);
        gpio_set_level(HX711_SCK_PIN, 0);
        esp_rom_delay_us(1);
    }

    // Send the 25th clock pulse to acknowledge the reading
    gpio_set_level(HX711_SCK_PIN, 1);
    esp_rom_delay_us(1);
    gpio_set_level(HX711_SCK_PIN, 0);

    // Convert to signed value
    data ^= 0x800000; // Flip MSB for signed data

    return data;
}

/* I2C Slave Initialization */
void i2c_slave_init()
{
    i2c_config_t conf_slave = {
        .mode = I2C_MODE_SLAVE,
        .sda_io_num = I2C_SLAVE_SDA_IO,
        .scl_io_num = I2C_SLAVE_SCL_IO,
        .sda_pullup_en = GPIO_PULLUP_ENABLE,
        .scl_pullup_en = GPIO_PULLUP_ENABLE,
        .slave = {
            .addr_10bit_en = 0,
            .slave_addr = I2C_SLAVE_ADDRESS
        },
    };

    ESP_ERROR_CHECK(i2c_param_config(I2C_SLAVE_NUM, &conf_slave));
    ESP_ERROR_CHECK(i2c_driver_install(I2C_SLAVE_NUM, conf_slave.mode,
                                       I2C_SLAVE_RX_BUF_LEN, I2C_SLAVE_TX_BUF_LEN, 0));
    ESP_LOGI(TAG, "I2C slave initialized at address 0x%X", I2C_SLAVE_ADDRESS);
}

/* LED Strip Configuration */
void configure_led()
{
    ESP_LOGI(TAG, "Configuring SK6812 LED...");
    led_strip_config_t strip_config = {
        .strip_gpio_num = SK6812_PIN,
        .max_leds = 1, // At least one LED
    };
    led_strip_rmt_config_t rmt_config = {
        .resolution_hz = 10 * 1000 * 1000, // 10MHz
        .flags.with_dma = false,
    };

    ESP_ERROR_CHECK(led_strip_new_rmt_device(&strip_config, &rmt_config, &led_strip));
    led_strip_clear(led_strip);
}

/* Set LED Color */
void set_led_color(uint8_t red, uint8_t green, uint8_t blue)
{
    led_strip_set_pixel(led_strip, 0, red, green, blue);
    led_strip_refresh(led_strip);
}

/* I2C Slave Task */
void i2c_slave_task(void *arg) {
    uint8_t buffer[21]; // Header + Slave ID + Data + Footer
    memset(buffer, 0, sizeof(buffer));

    while (1) {
        // Wait for data request from master
        uint8_t dummy[1];
        int len = i2c_slave_read_buffer(I2C_SLAVE_NUM, dummy, sizeof(dummy), portMAX_DELAY);
        if (len > 0) {
            // Read HX711 for weight
            int32_t weight = hx711_read();

            int32_t temperature = 0;
            uint32_t humidity = 0;
            int32_t pressure = 0;

            if (bme280_connected) {
                uint8_t data[8];
                bme280_read_register(BME280_REG_DATA, data, 8);

                int32_t adc_T = (data[3] << 12) | (data[4] << 4) | (data[5] >> 4);
                int32_t adc_P = (data[0] << 12) | (data[1] << 4) | (data[2] >> 4);
                int32_t adc_H = (data[6] << 8) | data[7];

                temperature = compensate_temperature(adc_T);
                pressure = compensate_pressure(adc_P);
                humidity = compensate_humidity(adc_H);
            } else {
                
                ESP_LOGW(TAG, "Skipping BME280 data retrieval as it's not connected.");
                set_led_color(128, 0, 128); // Purple LED for missing sensor
                vTaskDelay(pdMS_TO_TICKS(1000));
                bmeFAIL++;
                if (bmeFAIL > 5) {
                    bmeFAIL = 0;
                    bme280_init(); // Try to reconnect
                    set_led_color(100, 100, 0);   // Orange LED for ready state
                }
                set_led_color(0, 0, 255);   // Blue LED for ready state
            }

            ESP_LOGI(TAG, "Slave ID: %d, Temperature: %.2f °C, Pressure: %.2f hPa, Humidity: %.2f%%, Weight: %.2f g",
                     slave_id, temperature / 100.0, pressure / 100.0, humidity / 1024.0, weight / 100.0);

            // Fill buffer with sensor data
            buffer[0] = 0xAB;               // Header
            buffer[1] = slave_id;           // Slave ID
            memcpy(&buffer[2], &temperature, sizeof(int32_t));
            memcpy(&buffer[6], &humidity, sizeof(uint32_t));
            memcpy(&buffer[10], &pressure, sizeof(int32_t));
            memcpy(&buffer[14], &weight, sizeof(int32_t));
            buffer[18] = 0xCD;              // Footer

            // Indicate activity with LED
            set_led_color(0, 255, 0); // Green for active
            vTaskDelay(pdMS_TO_TICKS(500));
            set_led_color(0, 0, 255); // Blue for ready state

            // Write data to I2C buffer
            i2c_slave_write_buffer(I2C_SLAVE_NUM, buffer, sizeof(buffer), portMAX_DELAY);
        }
    }
}



/* Main Function */
void app_main(void)
{
    ESP_LOGI(TAG, "Starting I2C Slave with HX711 and SK6812 LED...");



    // Initialize HX711, I2C, and LED
    hx711_init();
    i2c_slave_init();
    configure_led();
    set_gpio_high();
    i2c_master_init();
    bme280_init();

    // Set initial LED state
    set_led_color(255, 0, 0); // Red for startup
    vTaskDelay(pdMS_TO_TICKS(1000));
    set_led_color(0, 0, 255); // Blue for ready state

    // Start I2C slave task
    xTaskCreate(i2c_slave_task, "i2c_slave_task", 4096, NULL, 10, NULL);
}

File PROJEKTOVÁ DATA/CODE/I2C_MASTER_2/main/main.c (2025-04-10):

#include <stdio.h>
#include <string.h>
#include <inttypes.h>
#include "freertos/FreeRTOS.h"
#include "freertos/task.h"
#include "driver/i2c.h"
#include "driver/gpio.h"
#include "esp_log.h"
#include "esp_wifi.h"
#include "esp_event.h"
#include "nvs_flash.h"
#include "esp_http_client.h"
#include "led_strip.h"

#define MAX_HIVE_ID                2
#define interval                   30000  // Interval between requests in milliseconds

#define I2C_MASTER_SCL_IO          38  // GPIO for I2C clock
#define I2C_MASTER_SDA_IO          39  // GPIO for I2C data
#define I2C_MASTER_NUM             I2C_NUM_0
#define I2C_MASTER_FREQ_HZ         100000
#define I2C_MASTER_TIMEOUT_MS      1000


#define RGB_LED_PIN                42  // GPIO for SK6812 RGB LED
#define MOSFET_PIN                 45  // GPIO for MOSFET control

#define WIFI_SSID                  "This"  // Replace with your Wi-Fi SSID
#define WIFI_PASS                  "12345679"  // Replace with your Wi-Fi password
#define WEB_SERVER_URL             "http://smarthives.fun/php/insert_data.php"  // Replace with your endpoint URL

static const char *TAG = "I2C_MASTER";
static led_strip_handle_t led_strip;

// Function Prototypes
void wifi_init(void);
void send_data_to_server(uint8_t slave_id, float temperature, float humidity, int32_t pressure, int32_t raw_weight);

/* Configure GPIO as output */
void configure_gpio(int gpio_num, int initial_level)
{
    gpio_config_t io_conf = {
        .pin_bit_mask = (1ULL << gpio_num),
        .mode = GPIO_MODE_OUTPUT,
        .pull_up_en = GPIO_PULLUP_DISABLE,
        .pull_down_en = GPIO_PULLDOWN_DISABLE,
        .intr_type = GPIO_INTR_DISABLE
    };
    ESP_ERROR_CHECK(gpio_config(&io_conf));
    gpio_set_level(gpio_num, initial_level);
    ESP_LOGI(TAG, "Configured GPIO %d as output with initial level %d.", gpio_num, initial_level);
}

/* LED Strip Configuration */
void configure_rgb_led()
{
    ESP_LOGI(TAG, "Configuring SK6812 RGB LED...");
    led_strip_config_t strip_config = {
        .strip_gpio_num = RGB_LED_PIN,
        .max_leds = 1, // At least one LED
    };
    led_strip_rmt_config_t rmt_config = {
        .resolution_hz = 10 * 1000 * 1000, // 10MHz
        .flags.with_dma = false,
    };

    ESP_ERROR_CHECK(led_strip_new_rmt_device(&strip_config, &rmt_config, &led_strip));
    led_strip_clear(led_strip);
}

/* Set RGB LED Color */
void set_led_color(uint8_t red, uint8_t green, uint8_t blue)
{
    led_strip_set_pixel(led_strip, 0, red, green, blue);
    led_strip_refresh(led_strip);
}

/* Initialize I2C Master */
void i2c_master_init()
{
    i2c_config_t conf = {
        .mode = I2C_MODE_MASTER,
        .sda_io_num = I2C_MASTER_SDA_IO,
        .scl_io_num = I2C_MASTER_SCL_IO,
        .sda_pullup_en = GPIO_PULLUP_ENABLE,
        .scl_pullup_en = GPIO_PULLUP_ENABLE,
        .master.clk_speed = I2C_MASTER_FREQ_HZ,
    };

    ESP_ERROR_CHECK(i2c_param_config(I2C_MASTER_NUM, &conf));
    ESP_ERROR_CHECK(i2c_driver_install(I2C_MASTER_NUM, conf.mode, 0, 0, 0));
    ESP_LOGI(TAG, "I2C master initialized.");
}

static void wifi_event_handler(void *arg, esp_event_base_t event_base, int32_t event_id, void *event_data)
{
    if (event_base == WIFI_EVENT && event_id == WIFI_EVENT_STA_START) {
        esp_wifi_connect();
        ESP_LOGI(TAG, "Attempting to connect to Wi-Fi...");
        set_led_color(255, 165, 0); // Orange: Connecting
    } else if (event_base == WIFI_EVENT && event_id == WIFI_EVENT_STA_DISCONNECTED) {
        esp_wifi_connect();
        ESP_LOGW(TAG, "Wi-Fi disconnected. Retrying...");
        set_led_color(255, 0, 0); // Red: Disconnected
    } else if (event_base == IP_EVENT && event_id == IP_EVENT_STA_GOT_IP) {
        ip_event_got_ip_t *event = (ip_event_got_ip_t *)event_data;
        ESP_LOGI(TAG, "Connected! Got IP: " IPSTR, IP2STR(&event->ip_info.ip));
        set_led_color(0, 255, 0); // Green: Connected
    }
}


/* Wi-Fi Initialization */
void wifi_init(void)
{
    esp_err_t ret = nvs_flash_init();
    if (ret == ESP_ERR_NVS_NO_FREE_PAGES || ret == ESP_ERR_NVS_NEW_VERSION_FOUND) {
        ESP_ERROR_CHECK(nvs_flash_erase());
        ret = nvs_flash_init();
    }
    ESP_ERROR_CHECK(ret);

    ESP_ERROR_CHECK(esp_netif_init());
    ESP_ERROR_CHECK(esp_event_loop_create_default());

    esp_netif_create_default_wifi_sta();
    wifi_init_config_t cfg = WIFI_INIT_CONFIG_DEFAULT();
    ESP_ERROR_CHECK(esp_wifi_init(&cfg));

    // Register the Wi-Fi event handler
    ESP_ERROR_CHECK(esp_event_handler_instance_register(WIFI_EVENT, ESP_EVENT_ANY_ID, &wifi_event_handler, NULL, NULL));
    ESP_ERROR_CHECK(esp_event_handler_instance_register(IP_EVENT, IP_EVENT_STA_GOT_IP, &wifi_event_handler, NULL, NULL));

    wifi_config_t wifi_config = {
        .sta = {
            .ssid = WIFI_SSID,
            .password = WIFI_PASS,
        },
    };
    ESP_ERROR_CHECK(esp_wifi_set_mode(WIFI_MODE_STA));
    ESP_ERROR_CHECK(esp_wifi_set_config(WIFI_IF_STA, &wifi_config));
    ESP_ERROR_CHECK(esp_wifi_start());

    ESP_LOGI(TAG, "Wi-Fi initialization complete.");
}


/* Send Data to Web Server */
void send_data_to_server(uint8_t slave_id, float temperature, float humidity, int32_t pressure, int32_t raw_weight)
{
    char post_data[256];
    snprintf(post_data, sizeof(post_data),
             "{\"slave_id\":%d,\"raw_weight\":%" PRId32 ",\"temperature\":%.2f,\"humidity\":%.2f,\"pressure\":%" PRId32 "}",
             slave_id, raw_weight, temperature, humidity, pressure);

    esp_http_client_config_t config = {
        .url = WEB_SERVER_URL,
    };
    esp_http_client_handle_t client = esp_http_client_init(&config);

    esp_http_client_set_method(client, HTTP_METHOD_POST);
    esp_http_client_set_header(client, "Content-Type", "application/json");
    esp_http_client_set_post_field(client, post_data, strlen(post_data));

    esp_err_t err = esp_http_client_perform(client);
    if (err == ESP_OK) {
        ESP_LOGI(TAG, "HTTP POST Status = %d", esp_http_client_get_status_code(client));
        set_led_color(0, 255, 0); // Green: Data sent successfully
    } else {
        ESP_LOGE(TAG, "HTTP POST request failed: %s", esp_err_to_name(err));
        set_led_color(255, 0, 0); // Red: HTTP POST failed
    }
    esp_http_client_cleanup(client);
}
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

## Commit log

2024-09-26 KICAD COMMIT
    [BMP280.step, ESP32-S3-MINI-1-N8.step, ESP32-S3-WROOM-1U.step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]
2024-10-03 added schematic
    [Master.kicad_sch]
2024-10-10 Small changes to the pcb(Master and Slave))
    [Master.kicad_pcb, Master.kicad_sch, Slave.kicad_pcb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]
2024-10-13 Added CAP
    [BOM_SLAVE.csv, Master.kicad_pcb, Master.kicad_sch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]
2024-10-14 From 0603 TO 0805 at power supply
    [Master.kicad_pcb, Master.kicad_sch]
2024-10-15 Changed bmp for bme
    [BME280.step, Master.csv, Master.kicad_pcb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]
2024-10-15 Added I2C PullUp Resistors
    [Master.kicad_pcb, Master.kicad_sch, Slave.kicad_pcb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]
2024-10-17 repaired HX711
    [ESP32-S3-MINI-1-N8.step, Master.kicad_pcb, Master.kicad_sch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]
2024-10-21 update both
    [both-B_Cu.gbr, both-B_Mask.gbr, both-B_Paste.gbr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]
2025-04-10 SETUP FOR HANDOVER1
    [Master.kicad_sch, Slave.kicad_sch]
2025-04-10 Handover setup 2
    [BME280.step, BMP280.step, BOM_SLAVE.csv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]
